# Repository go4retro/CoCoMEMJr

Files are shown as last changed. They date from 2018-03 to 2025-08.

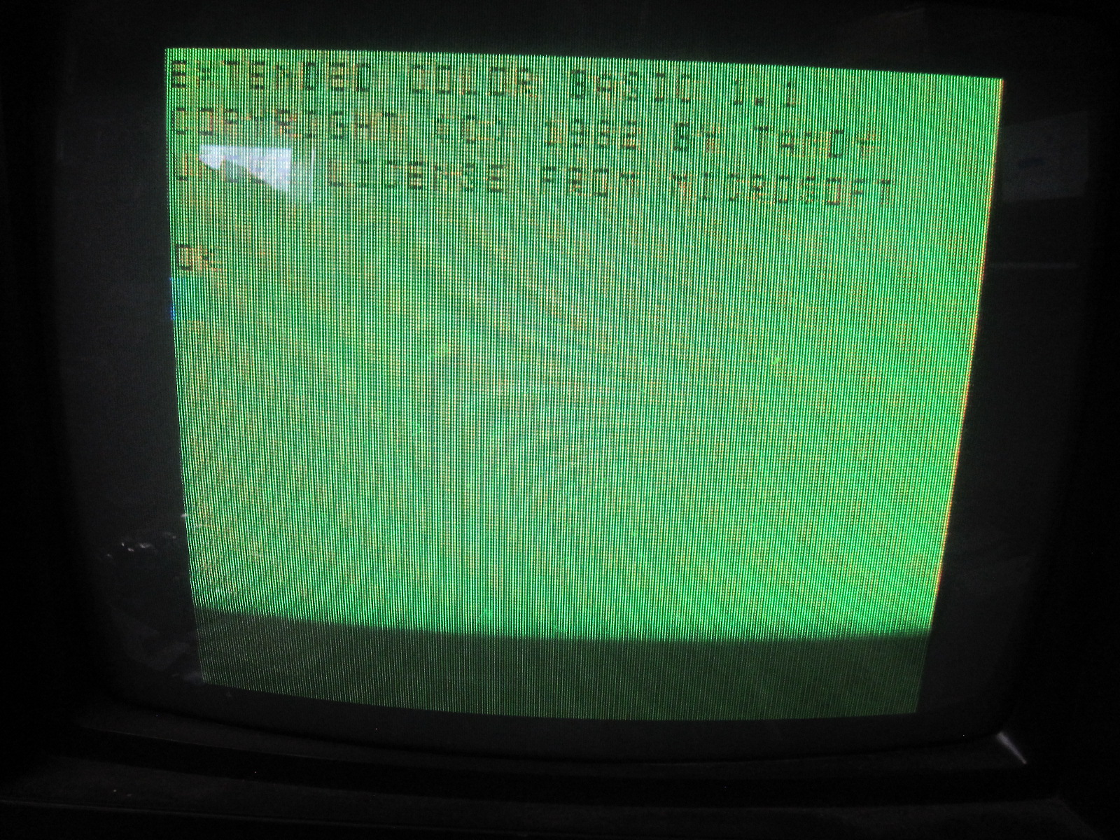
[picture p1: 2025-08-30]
media/IMG_8341.JPG

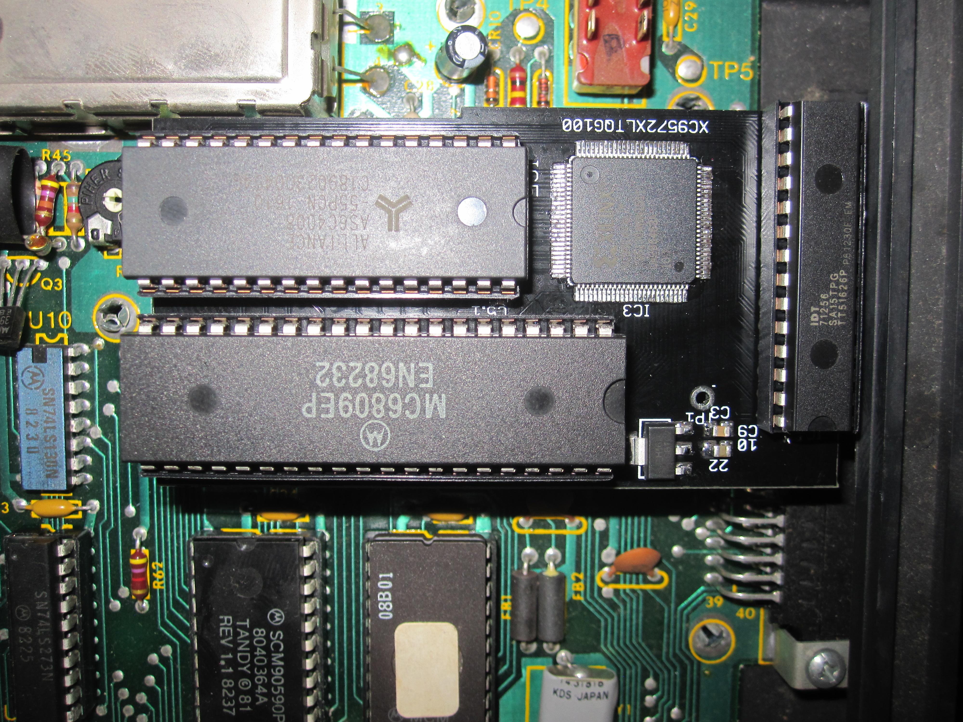
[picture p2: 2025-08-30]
media/IMG_8122.JPG

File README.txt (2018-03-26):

TANDY Color Computer 1 and 2/Dragon 2MB RAM Expansion System

Copyright (C) 2017-18  Jim Brain, RETRO Innovations

These files are free designs; you can redistribute them and/or modify
them under the terms of the Creative Commons Attribution-ShareAlike 
4.0 International License.

You should have received a copy of the license along with this
work. If not, see <http://creativecommons.org/licenses/by-sa/4.0/>.

These files are distributed in the hope that they will be useful,
but WITHOUT ANY WARRANTY; without even the implied warranty of
MERCHANTABILITY or FITNESS FOR A PARTICULAR PURPOSE.  See the
license for more details.

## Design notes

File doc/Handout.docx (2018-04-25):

COCOMEM Jr.

Memory expansion and MMU for the TANDY Color Computer™ 1 and 2 and Dragon Data™ 32/64 and TANO Dragon

# Features

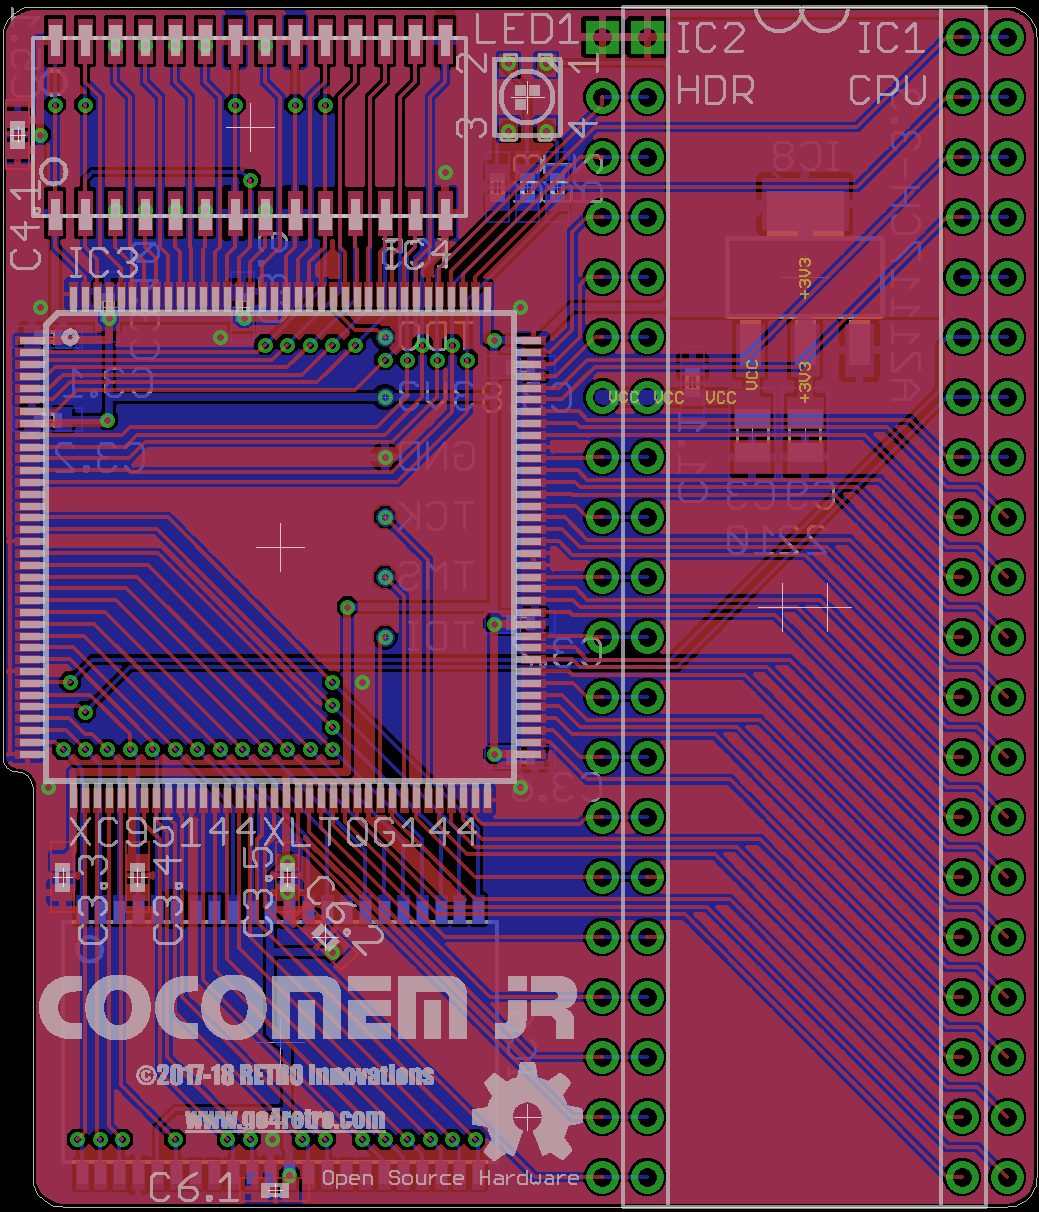
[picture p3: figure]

- 2 Megabyte RAM Expansion
- TANDY Color Computer™ 3-compatible MMU
- Installs internal to Color Computer (in CPU socket)
- CocoMEM MMU+ capability (32 tasks, protected memory)
- Internal Color Computer memory can be relocated via MMU

Offered by:

RETRO Innovations

Contemporary Gear for Classic Machines

www.go4retro.com

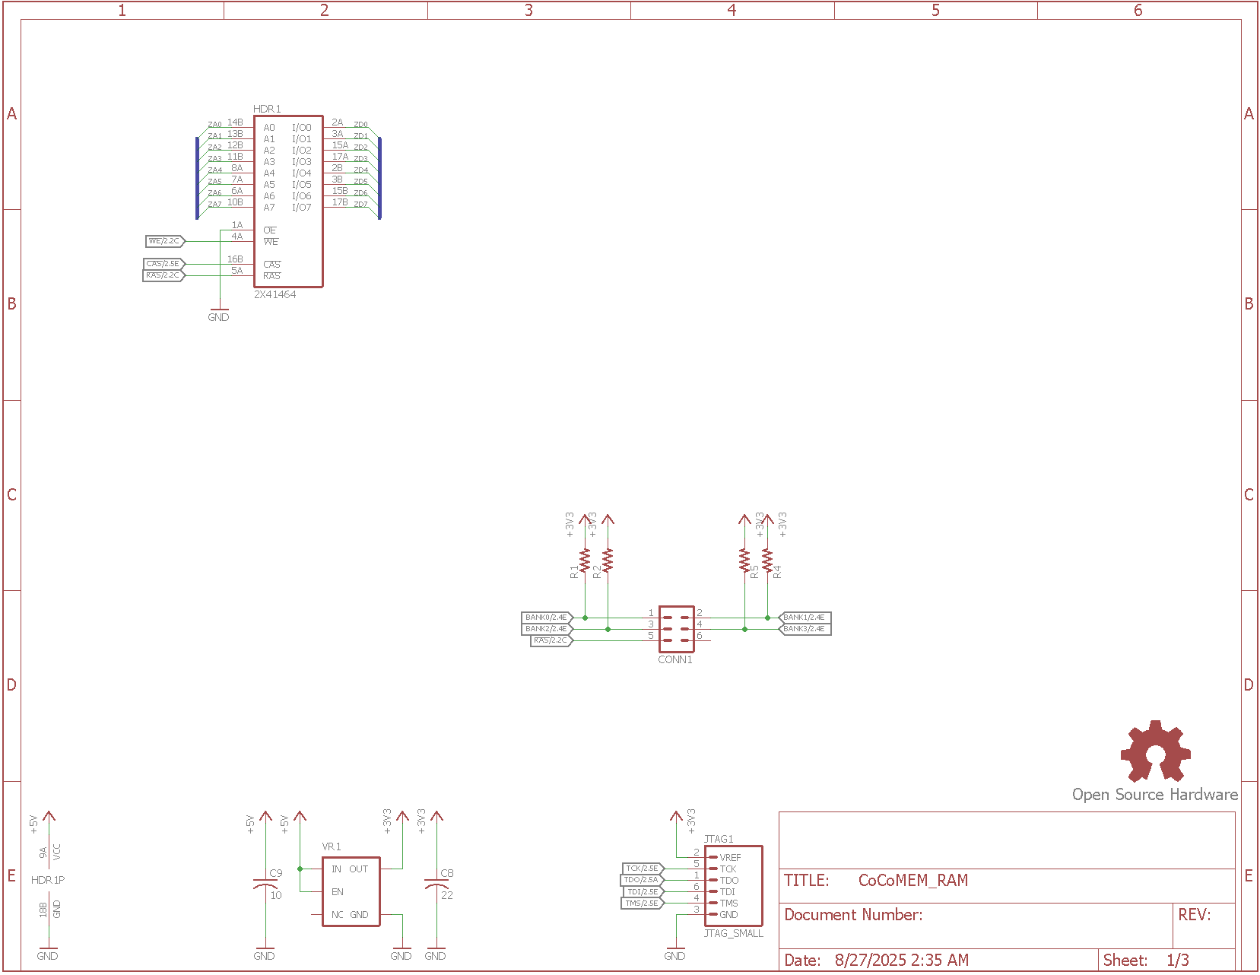
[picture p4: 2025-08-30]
media/CoCoMEM_RAM Schematic.png

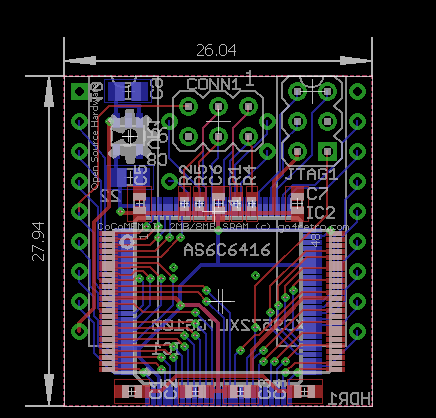
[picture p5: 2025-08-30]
media/CoCoMEM_RAM PCB.png

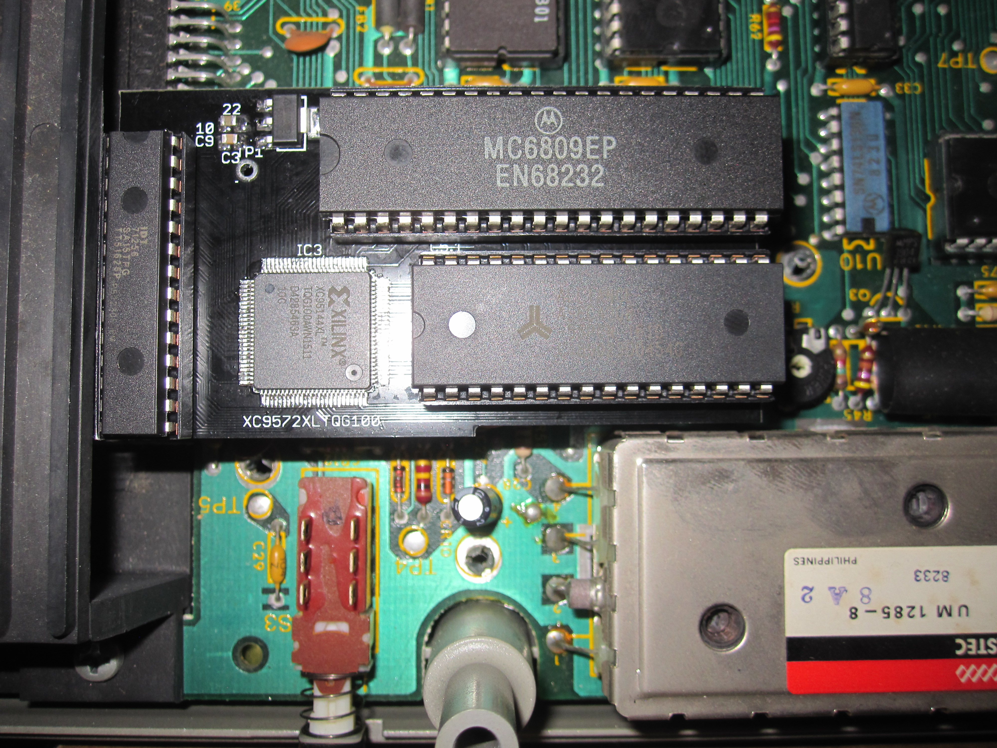
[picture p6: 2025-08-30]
media/IMG_8124 - Copy.JPG

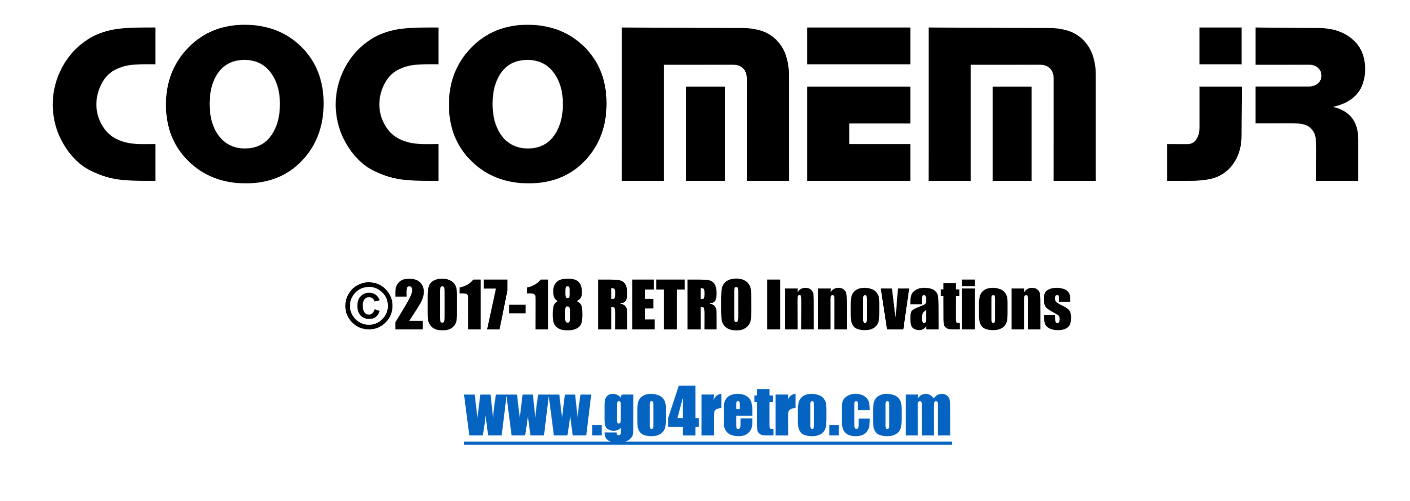
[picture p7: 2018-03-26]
pcb/CocoMemJr.PNG

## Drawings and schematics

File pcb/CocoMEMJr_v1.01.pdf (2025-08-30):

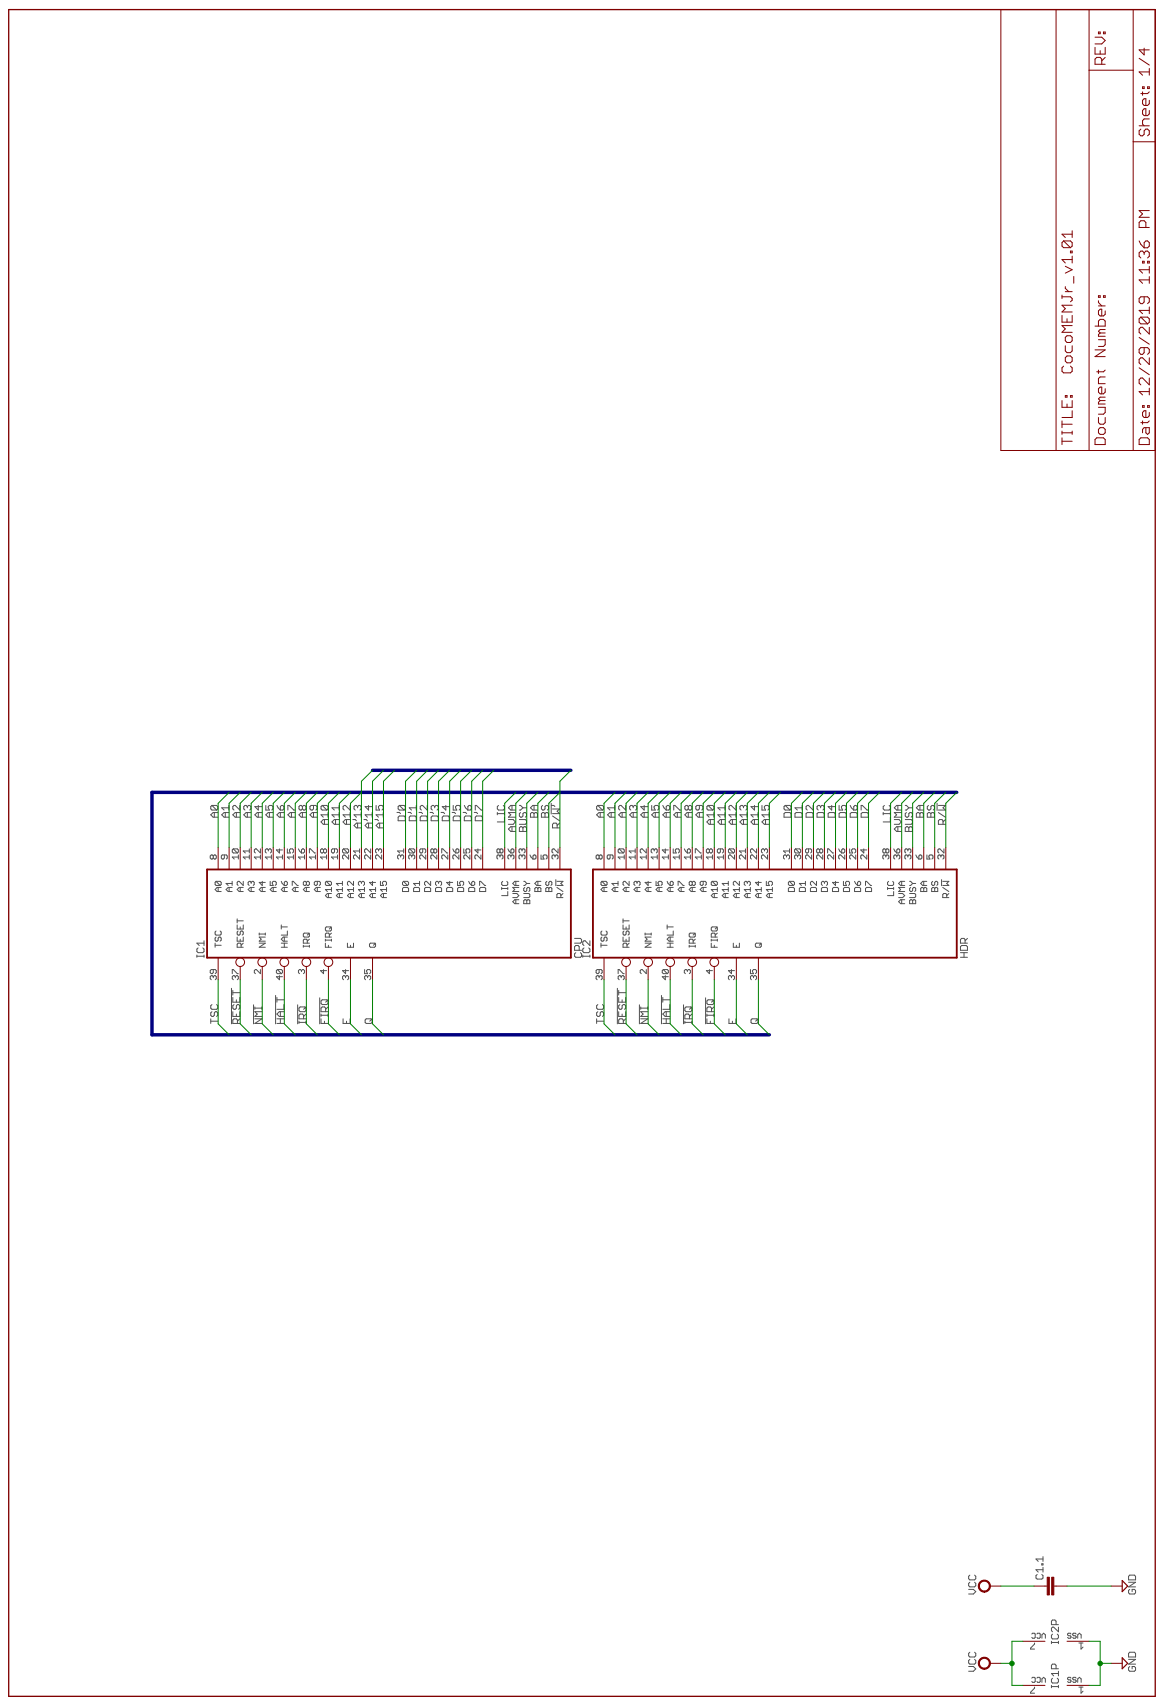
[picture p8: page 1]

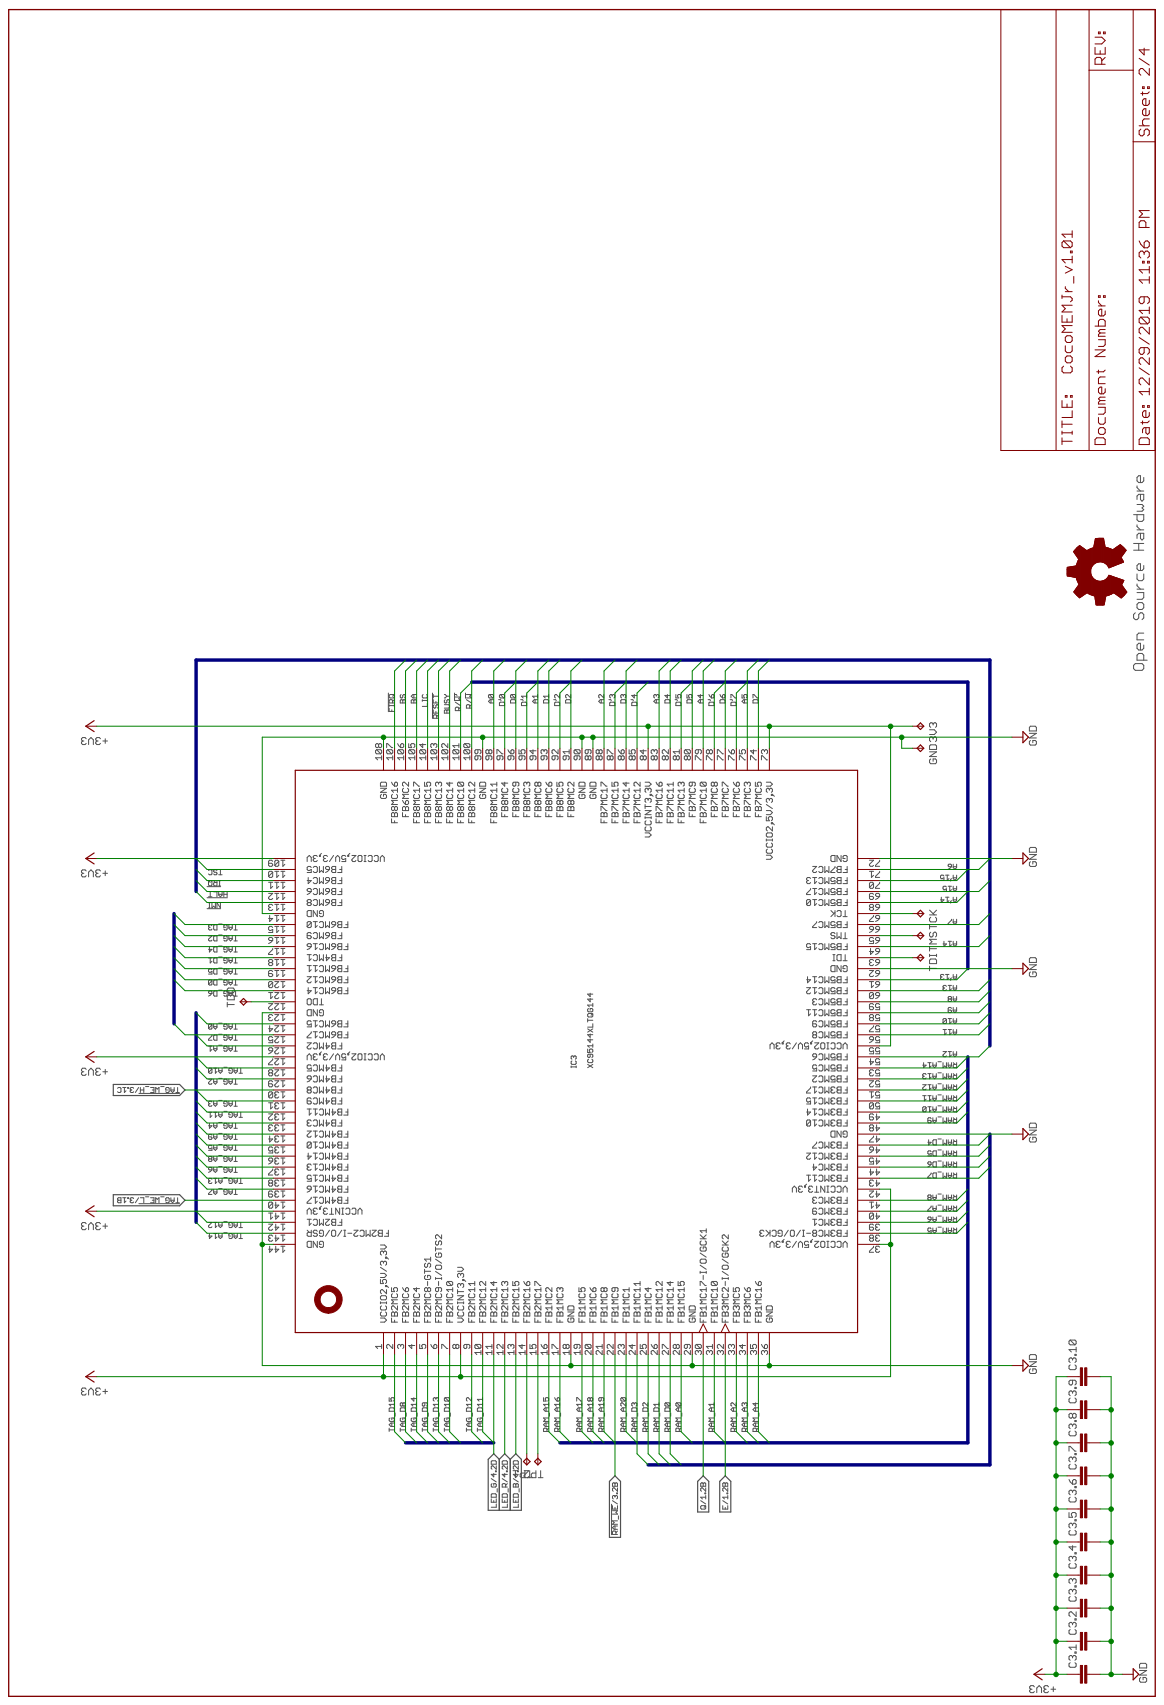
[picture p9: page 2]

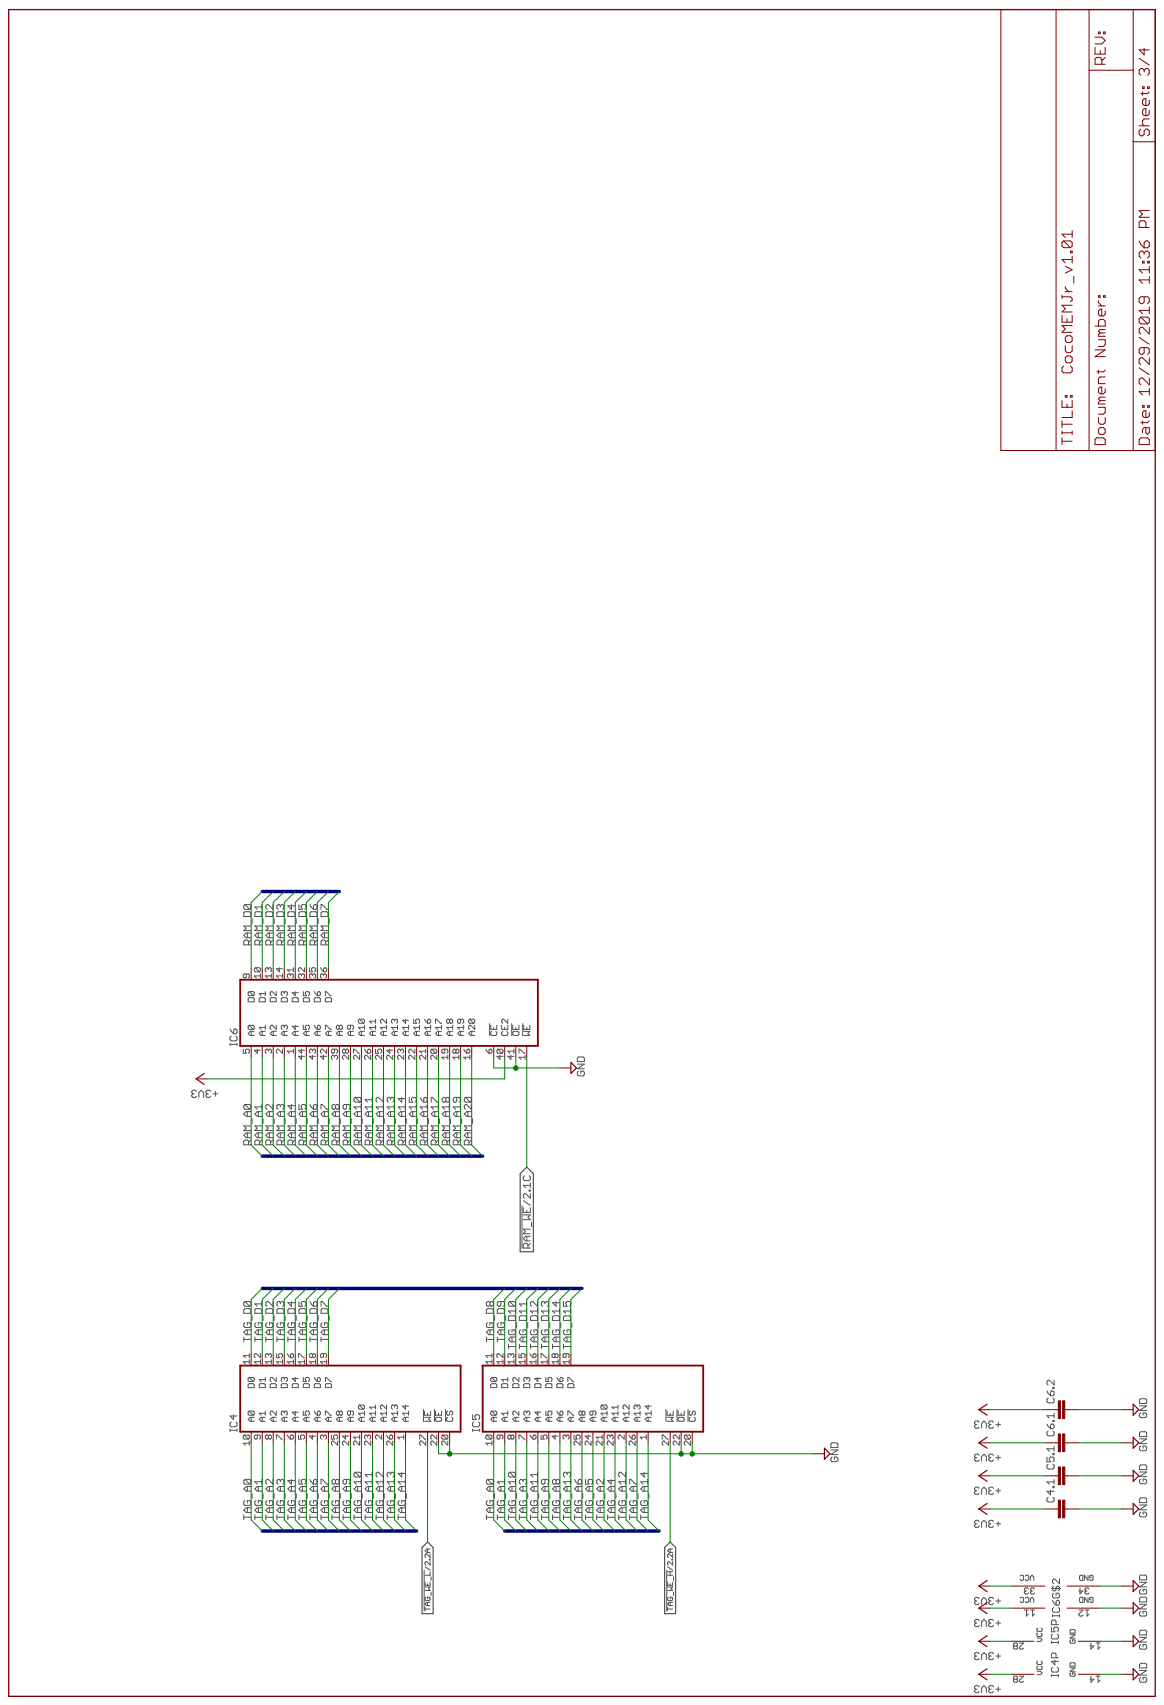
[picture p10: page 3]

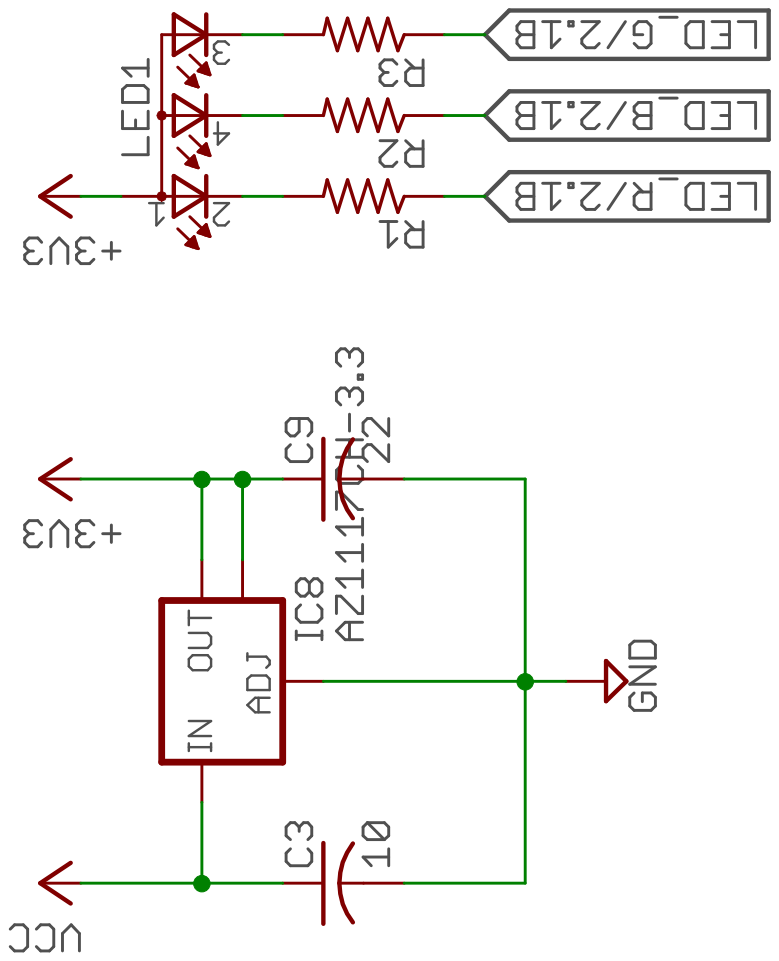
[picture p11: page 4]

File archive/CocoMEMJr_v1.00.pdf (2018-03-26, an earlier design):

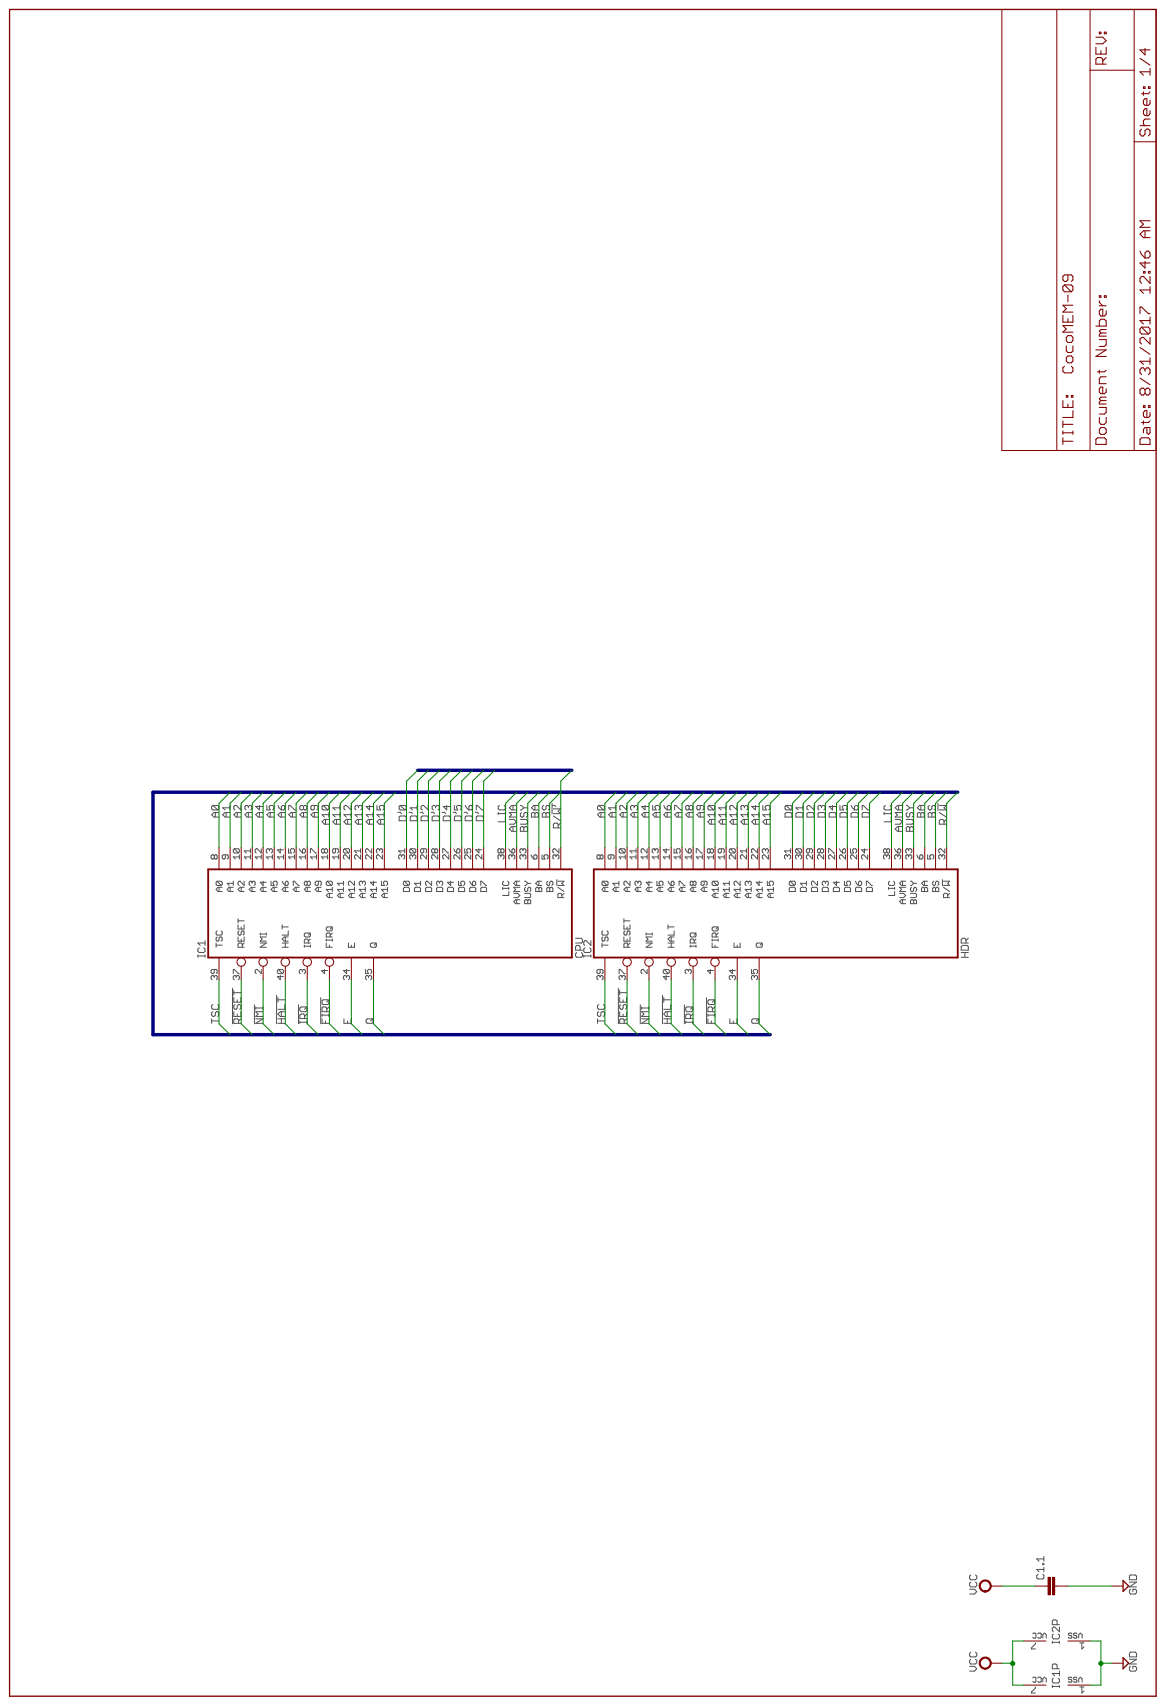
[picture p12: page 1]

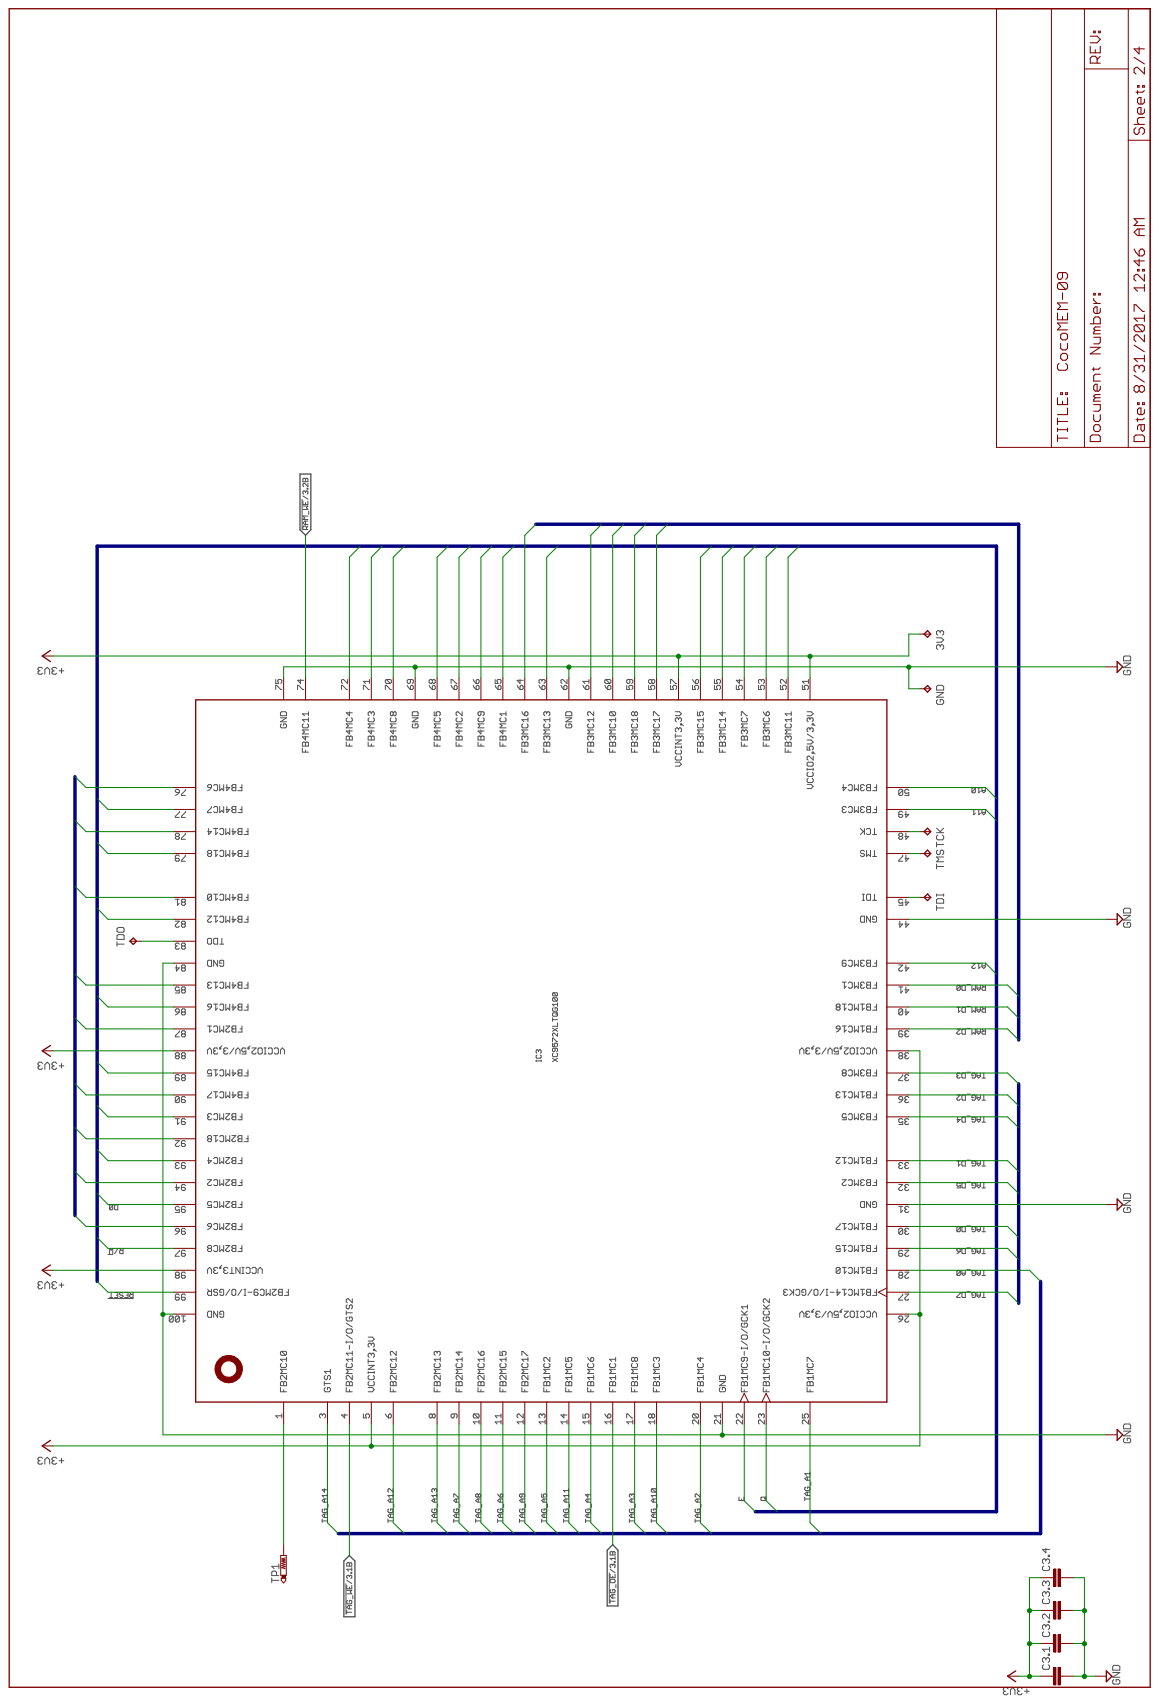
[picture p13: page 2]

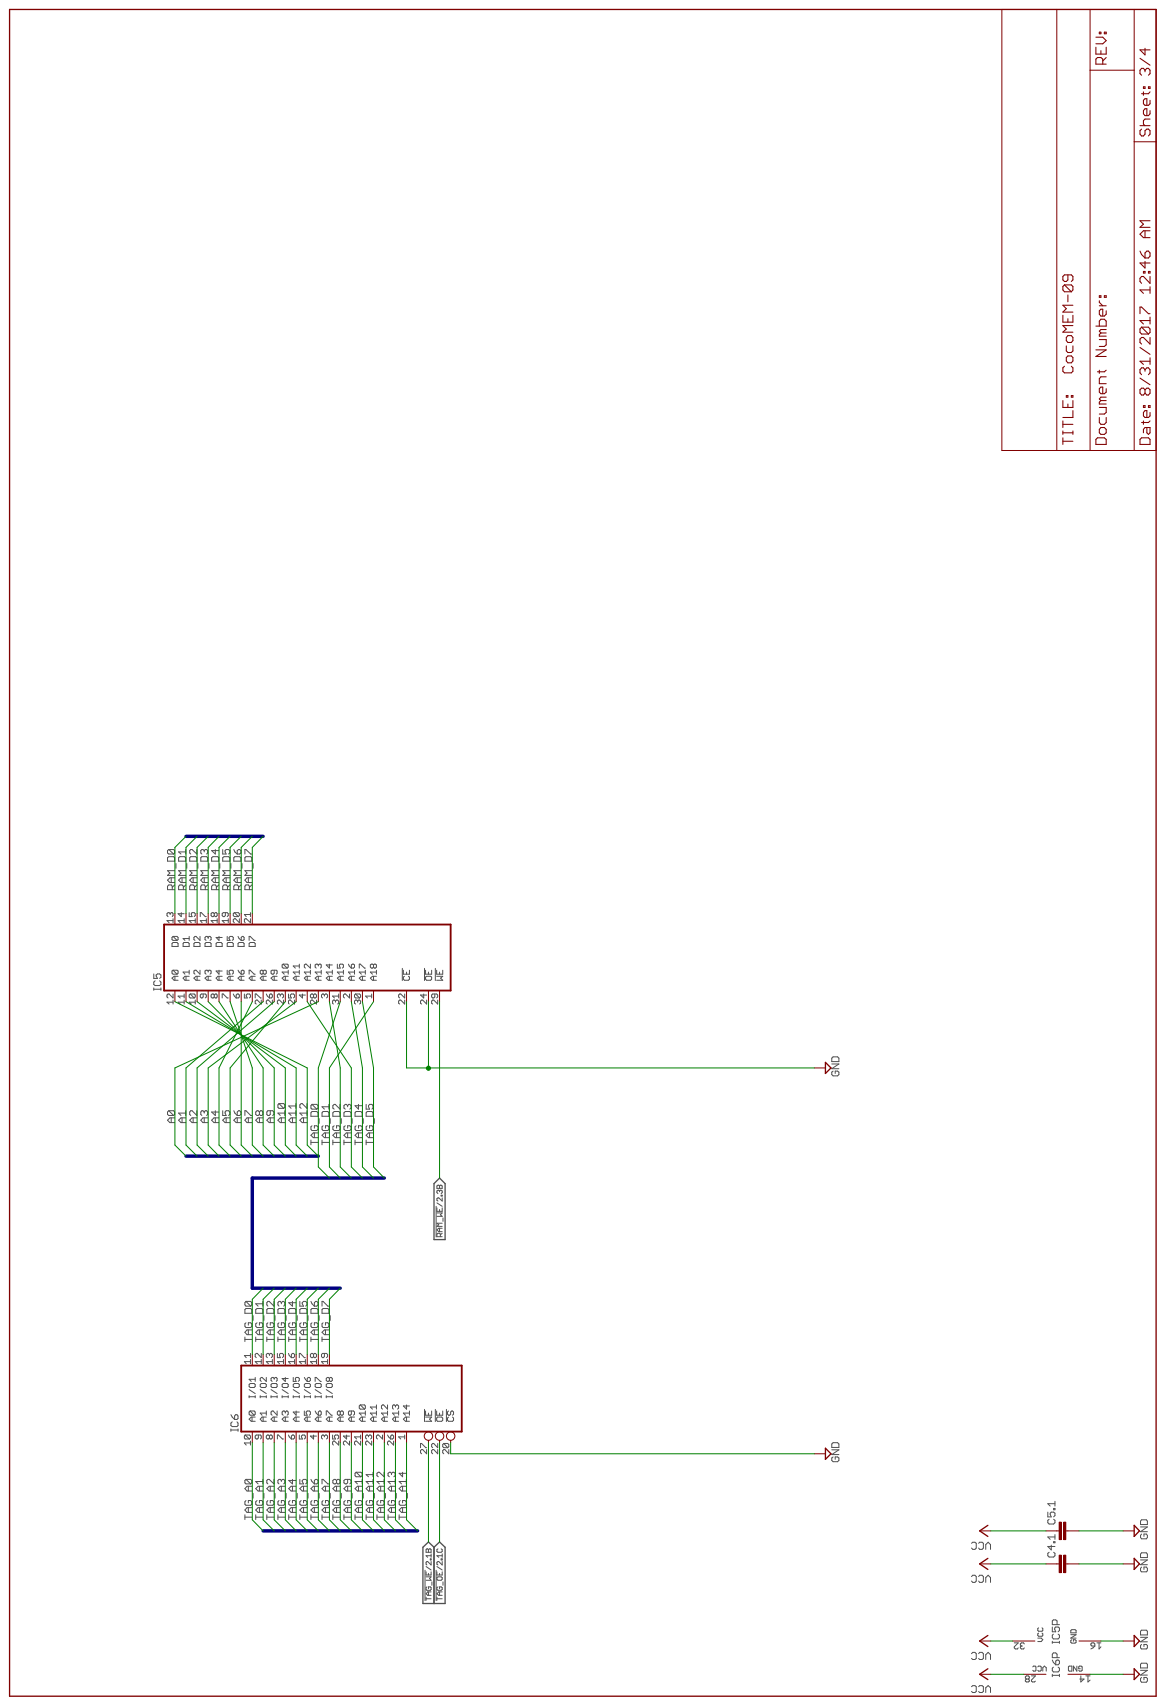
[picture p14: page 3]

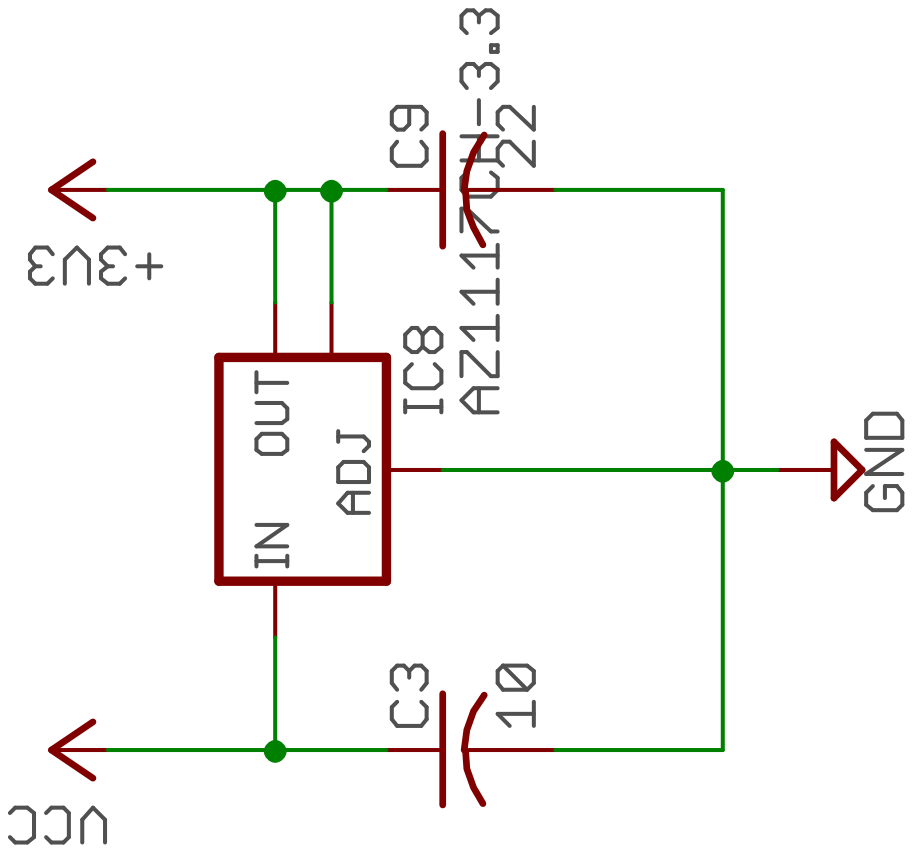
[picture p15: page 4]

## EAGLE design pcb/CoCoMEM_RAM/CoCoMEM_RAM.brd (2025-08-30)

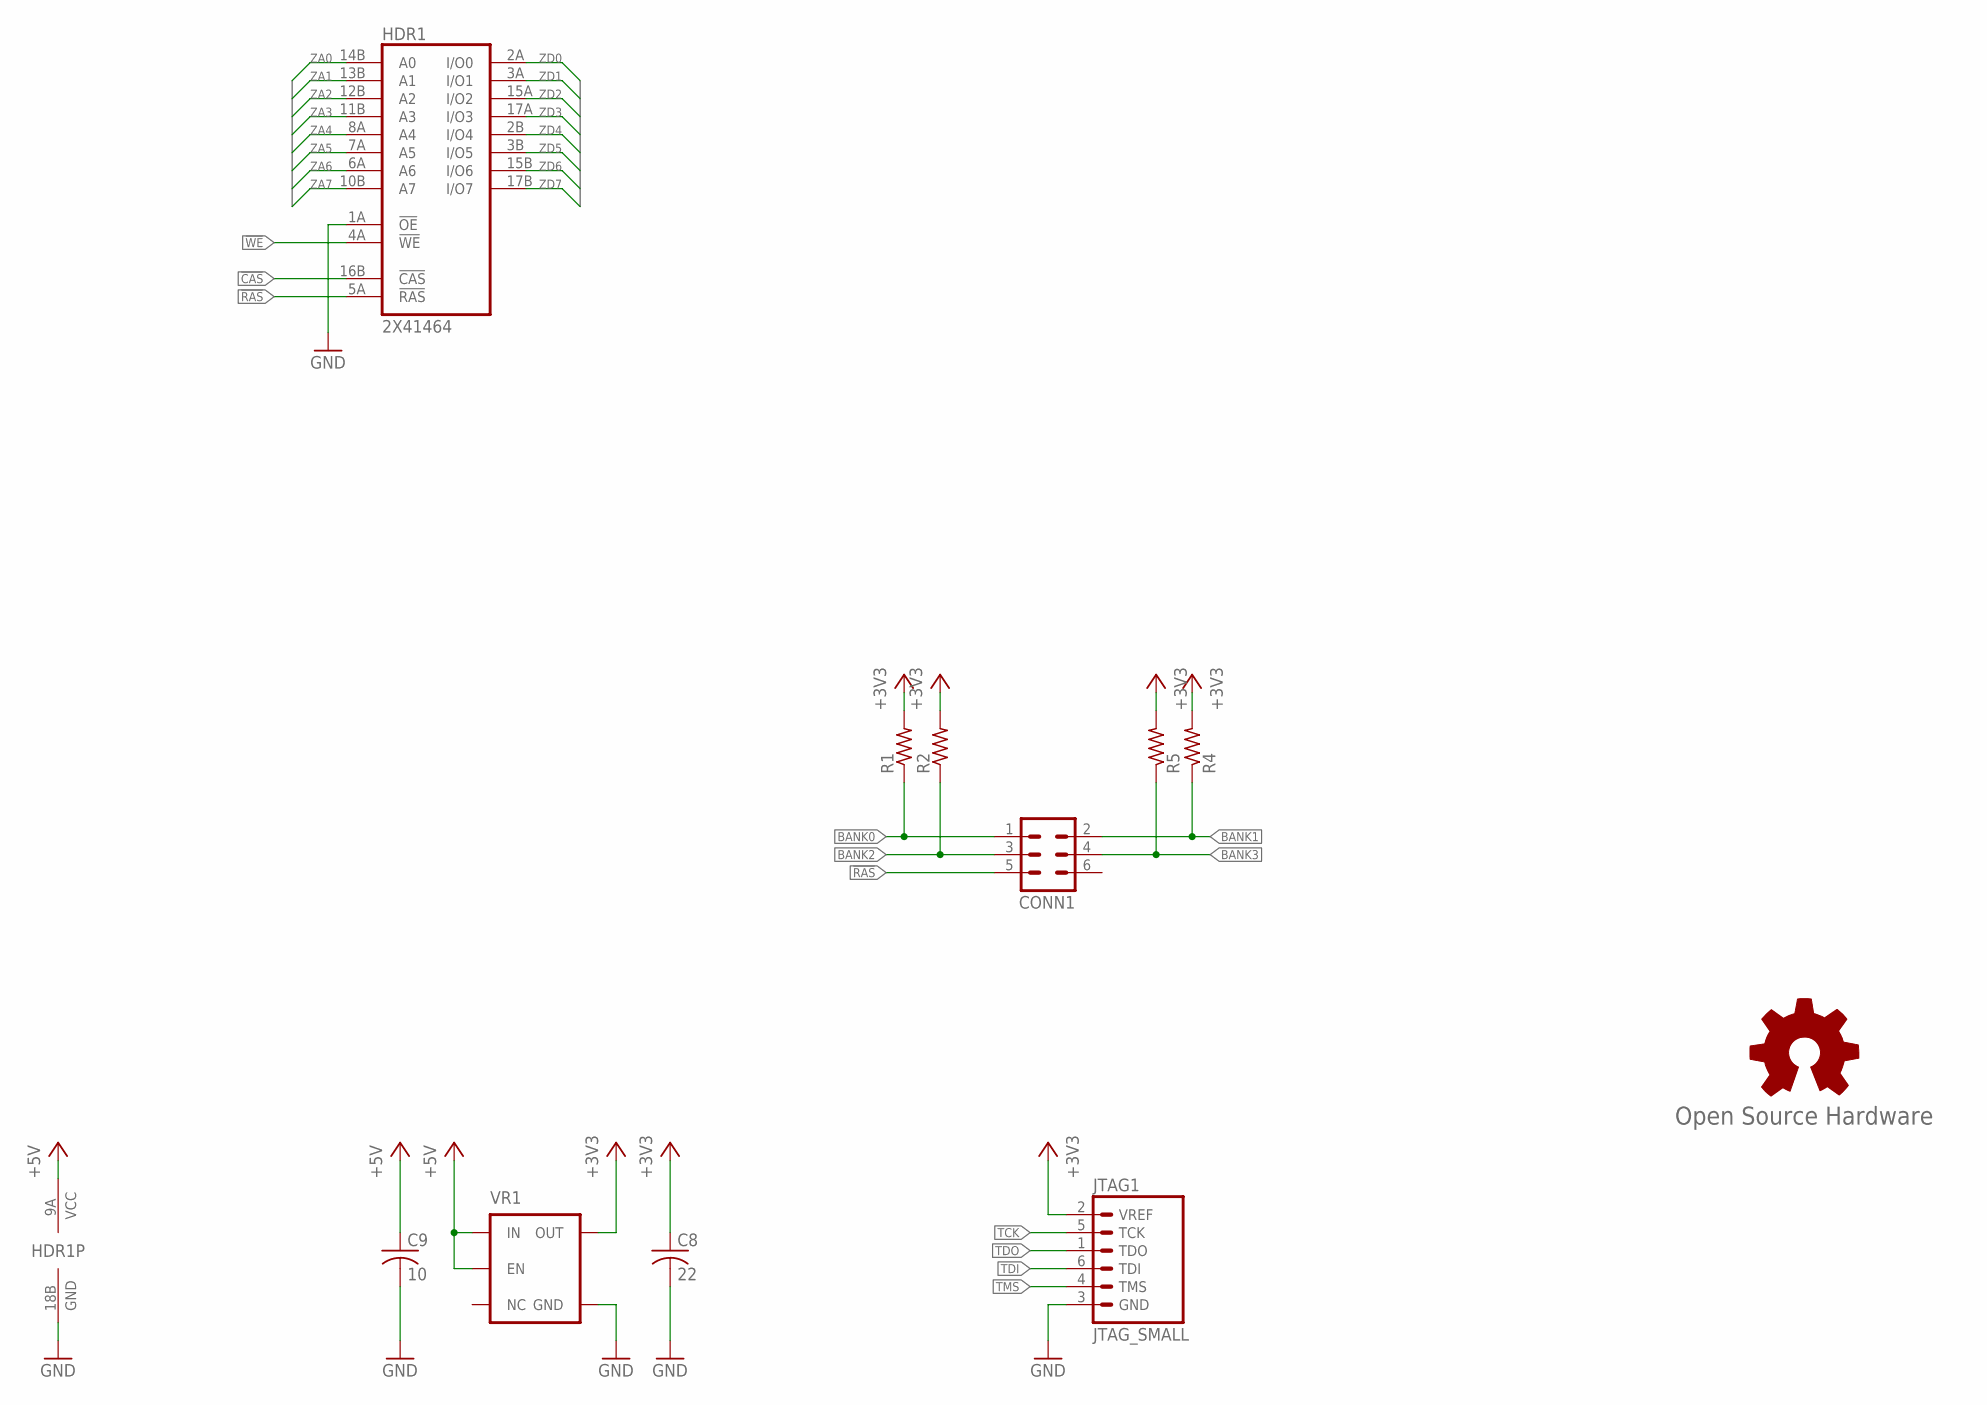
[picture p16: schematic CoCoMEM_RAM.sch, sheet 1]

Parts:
C8: 22; C0805
C9: 10; C0805
CONN1: MA03-2
GOLD_ORB_SM1: Open Source Hardware; OSHW_5MM
HDR1: 2X41464; 2XDIL18_REV
JTAG1: JTAG_SMALL; JTAG-6
R1, R2, R4, R5: R-US_R0402; R0402
VR1: V_REG_TPS76433SOT23-5; SOT23-5

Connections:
!CAS: HDR1.16B (!CAS); also elsewhere on the board
!RAS: CONN1.5, HDR1.5A (!RAS); also elsewhere on the board
!WE: HDR1.4A (!WE); also elsewhere on the board
+3V3: C8.1, JTAG1.2 (VREF), R1.2, R2.2, R4.2, R5.2, VR1.5 (OUT); also elsewhere on the board
+5V: C9.1, HDR1.9A (VCC), VR1.1 (IN), VR1.3 (EN)
BANK0: CONN1.1, R1.1; also elsewhere on the board
BANK1: CONN1.2, R4.1; also elsewhere on the board
BANK2: CONN1.3, R2.1; also elsewhere on the board
BANK3: CONN1.4, R5.1; also elsewhere on the board
GND: C8.2, C9.2, HDR1.1A (!OE), HDR1.18B (GND), JTAG1.3 (GND), VR1.2 (GND); also elsewhere on the board
TCK: JTAG1.5 (TCK); also elsewhere on the board
TDI: JTAG1.6 (TDI); also elsewhere on the board
TDO: JTAG1.1 (TDO); also elsewhere on the board
TMS: JTAG1.4 (TMS); also elsewhere on the board
ZA0: HDR1.14B (A0); also elsewhere on the board
ZA1: HDR1.13B (A1); also elsewhere on the board
ZA2: HDR1.12B (A2); also elsewhere on the board
ZA3: HDR1.11B (A3); also elsewhere on the board
ZA4: HDR1.8A (A4); also elsewhere on the board
ZA5: HDR1.7A (A5); also elsewhere on the board
ZA6: HDR1.6A (A6); also elsewhere on the board
ZA7: HDR1.10B (A7); also elsewhere on the board
ZD0: HDR1.2A (I/O0); also elsewhere on the board
ZD1: HDR1.3A (I/O1); also elsewhere on the board
ZD2: HDR1.15A (I/O2); also elsewhere on the board
ZD3: HDR1.17A (I/O3); also elsewhere on the board
ZD4: HDR1.2B (I/O4); also elsewhere on the board
ZD5: HDR1.3B (I/O5); also elsewhere on the board
ZD6: HDR1.15B (I/O6); also elsewhere on the board
ZD7: HDR1.17B (I/O7); also elsewhere on the board

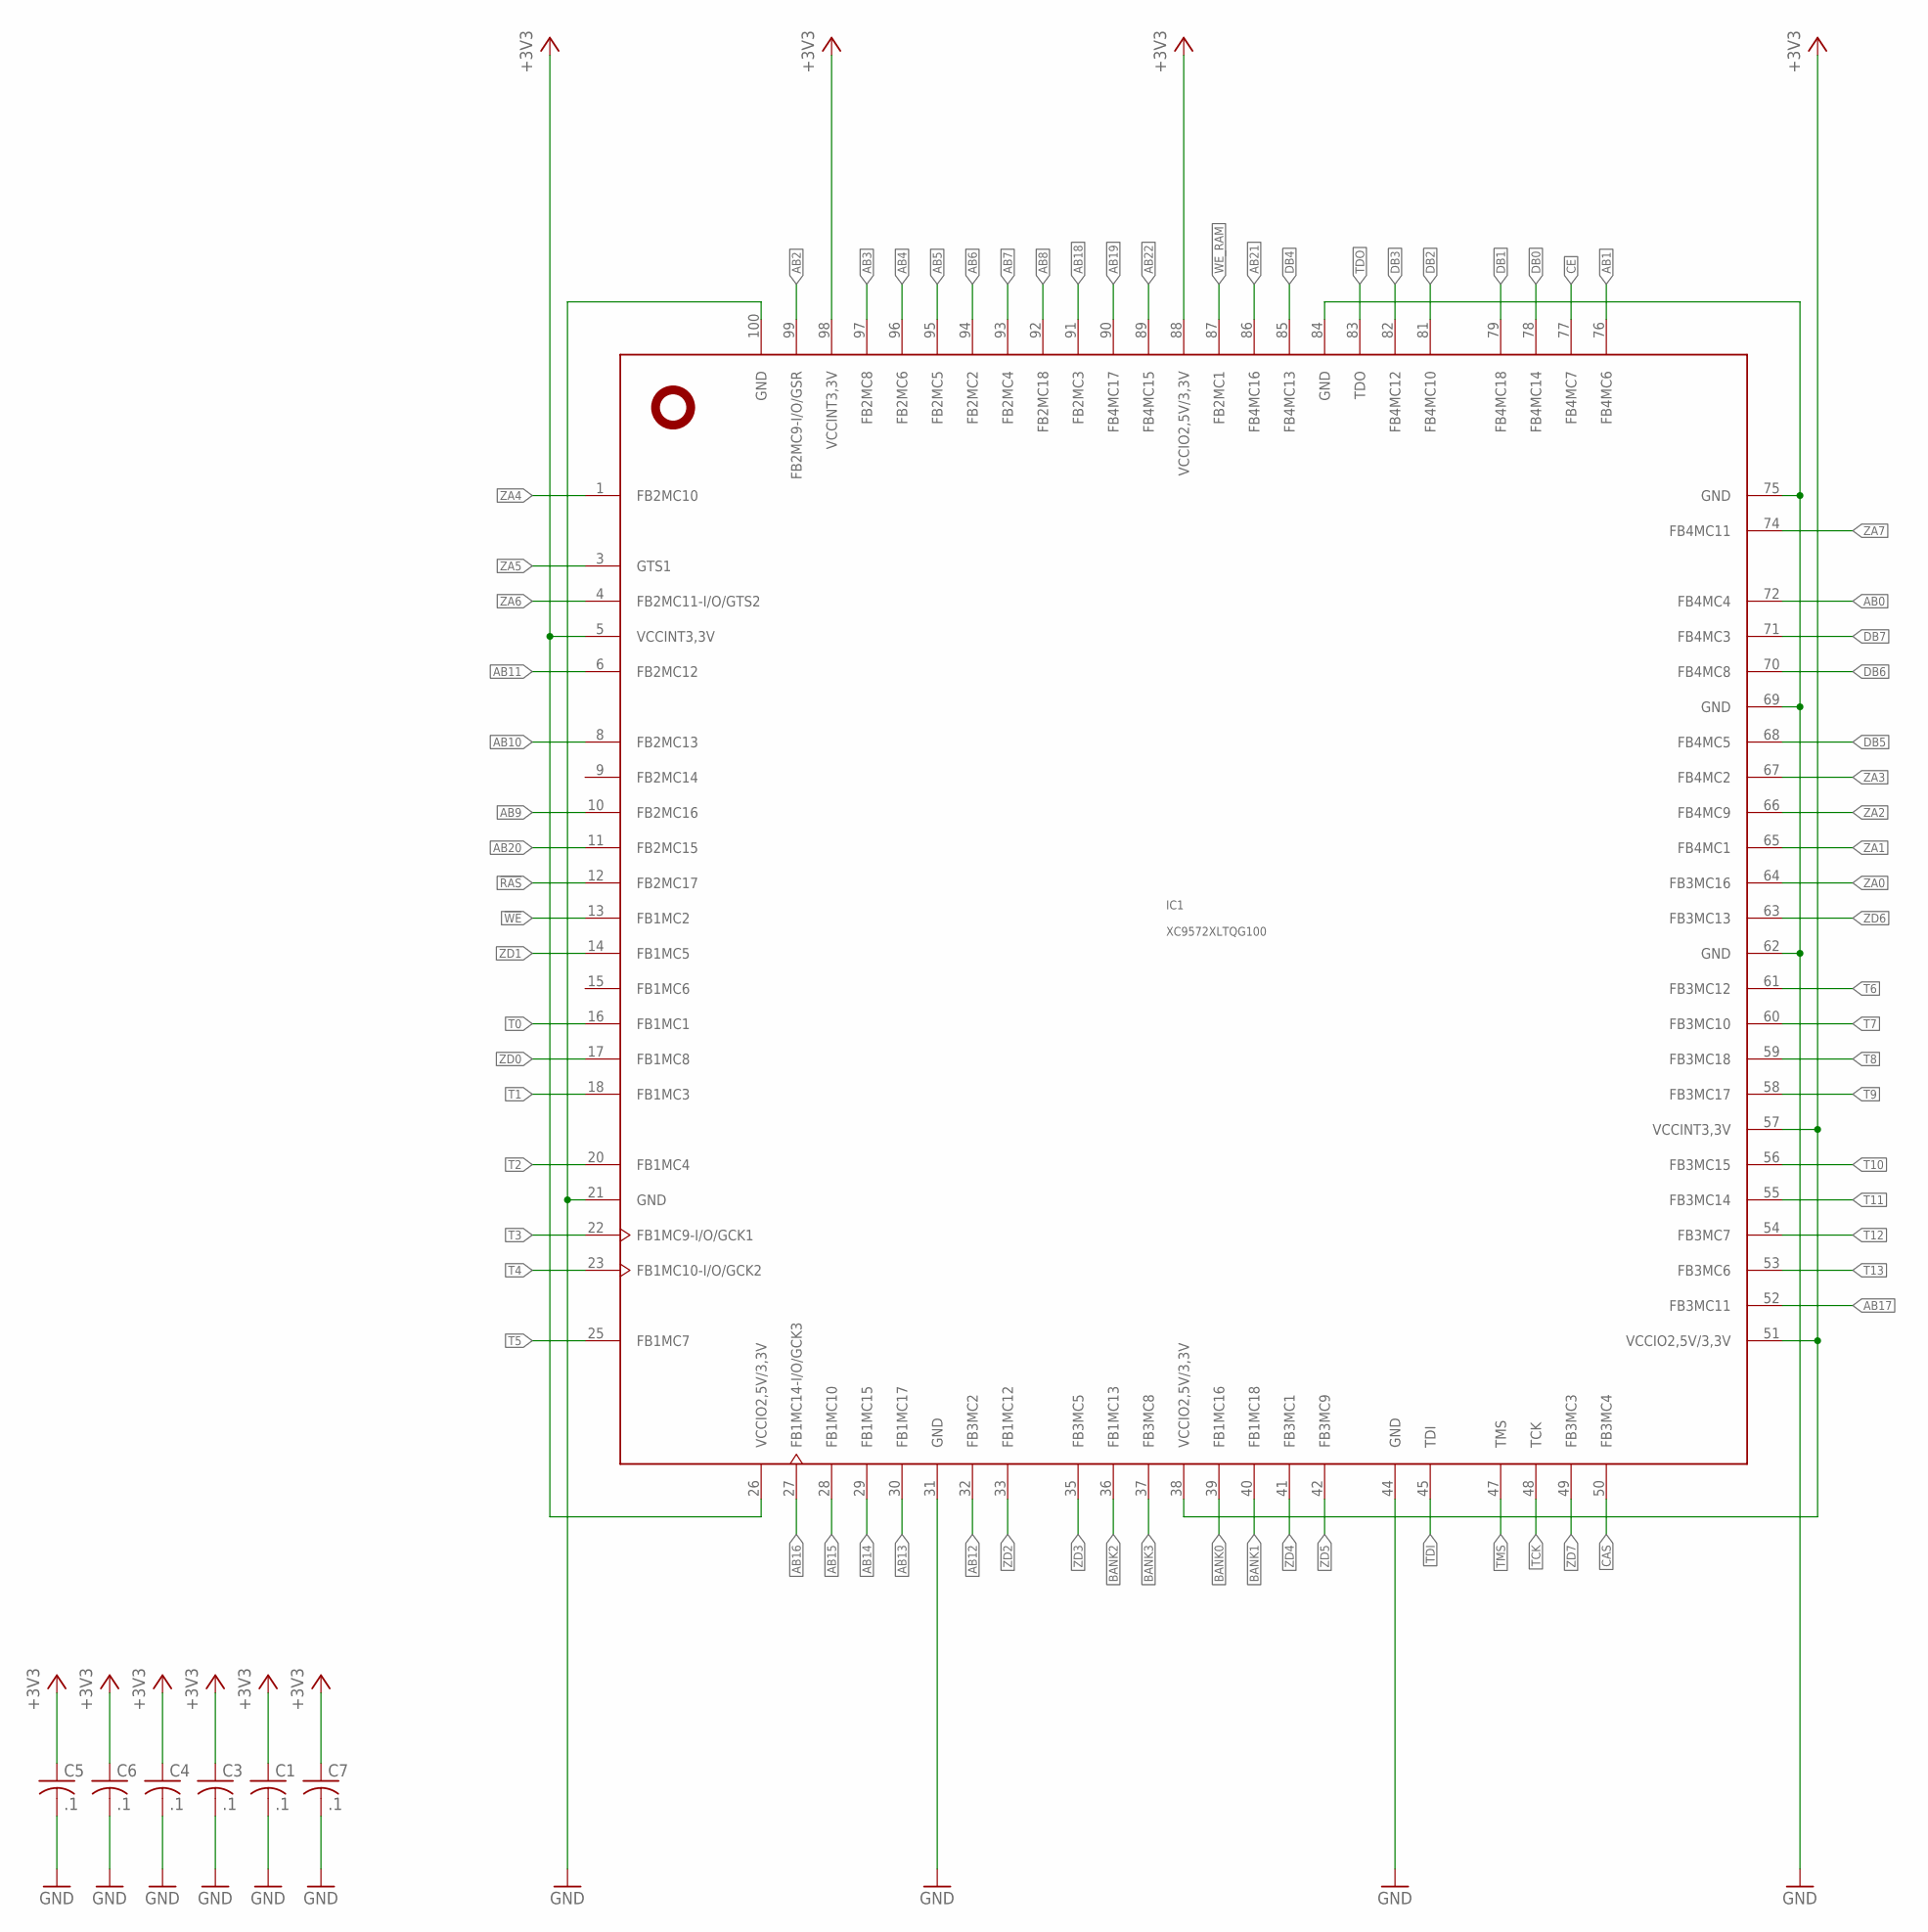
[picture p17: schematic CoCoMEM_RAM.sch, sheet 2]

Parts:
C1, C3, C4, C5, C6, C7: .1; C0603
IC1: XC9572XLTQG100; TQFP100

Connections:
!CAS: IC1.50 (FB3MC4); also elsewhere on the board
!CE: IC1.77 (FB4MC7); also elsewhere on the board
!RAS: IC1.12 (FB2MC17); also elsewhere on the board
!WE: IC1.13 (FB1MC2); also elsewhere on the board
!WE_RAM: IC1.87 (FB2MC1); also elsewhere on the board
+3V3: C1.1, C3.1, C4.1, C5.1, C6.1, C7.1, IC1.5 (VCCINT3,3V), IC1.26 (VCCIO2,5V/3,3V), IC1.38 (VCCIO2,5V/3,3V), IC1.51 (VCCIO2,5V/3,3V), IC1.57 (VCCINT3,3V), IC1.88 (VCCIO2,5V/3,3V), IC1.98 (VCCINT3,3V); also elsewhere on the board
AB0: IC1.72 (FB4MC4); also elsewhere on the board
AB1: IC1.76 (FB4MC6); also elsewhere on the board
AB2: IC1.99 (FB2MC9-I/O/GSR); also elsewhere on the board
AB3: IC1.97 (FB2MC8); also elsewhere on the board
AB4: IC1.96 (FB2MC6); also elsewhere on the board
AB5: IC1.95 (FB2MC5); also elsewhere on the board
AB6: IC1.94 (FB2MC2); also elsewhere on the board
AB7: IC1.93 (FB2MC4); also elsewhere on the board
AB8: IC1.92 (FB2MC18); also elsewhere on the board
AB9: IC1.10 (FB2MC16); also elsewhere on the board
AB10: IC1.8 (FB2MC13); also elsewhere on the board
AB11: IC1.6 (FB2MC12); also elsewhere on the board
AB12: IC1.32 (FB3MC2); also elsewhere on the board
AB13: IC1.30 (FB1MC17); also elsewhere on the board
AB14: IC1.29 (FB1MC15); also elsewhere on the board
AB15: IC1.28 (FB1MC10); also elsewhere on the board
AB16: IC1.27 (FB1MC14-I/O/GCK3); also elsewhere on the board
AB17: IC1.52 (FB3MC11); also elsewhere on the board
AB18: IC1.91 (FB2MC3); also elsewhere on the board
AB19: IC1.90 (FB4MC17); also elsewhere on the board
AB20: IC1.11 (FB2MC15); also elsewhere on the board
AB21: IC1.86 (FB4MC16); also elsewhere on the board
AB22: IC1.89 (FB4MC15); also elsewhere on the board
BANK0: IC1.39 (FB1MC16); also elsewhere on the board
BANK1: IC1.40 (FB1MC18); also elsewhere on the board
BANK2: IC1.36 (FB1MC13); also elsewhere on the board
BANK3: IC1.37 (FB3MC8); also elsewhere on the board
DB0: IC1.78 (FB4MC14); also elsewhere on the board
DB1: IC1.79 (FB4MC18); also elsewhere on the board
DB2: IC1.81 (FB4MC10); also elsewhere on the board
DB3: IC1.82 (FB4MC12); also elsewhere on the board
DB4: IC1.85 (FB4MC13); also elsewhere on the board
DB5: IC1.68 (FB4MC5); also elsewhere on the board
DB6: IC1.70 (FB4MC8); also elsewhere on the board
DB7: IC1.71 (FB4MC3); also elsewhere on the board
GND: C1.2, C3.2, C4.2, C5.2, C6.2, C7.2, IC1.21 (GND), IC1.31 (GND), IC1.44 (GND), IC1.62 (GND), IC1.69 (GND), IC1.75 (GND), IC1.84 (GND), IC1.100 (GND); also elsewhere on the board
T0: IC1.16 (FB1MC1)
T1: IC1.18 (FB1MC3)
T2: IC1.20 (FB1MC4)
T3: IC1.22 (FB1MC9-I/O/GCK1)
T4: IC1.23 (FB1MC10-I/O/GCK2)
T5: IC1.25 (FB1MC7)
T6: IC1.61 (FB3MC12)
T7: IC1.60 (FB3MC10)
T8: IC1.59 (FB3MC18)
T9: IC1.58 (FB3MC17)
T10: IC1.56 (FB3MC15)
T11: IC1.55 (FB3MC14)
T12: IC1.54 (FB3MC7)
T13: IC1.53 (FB3MC6)
TCK: IC1.48 (TCK); also elsewhere on the board
TDI: IC1.45 (TDI); also elsewhere on the board
TDO: IC1.83 (TDO); also elsewhere on the board
TMS: IC1.47 (TMS); also elsewhere on the board
ZA0: IC1.64 (FB3MC16); also elsewhere on the board
ZA1: IC1.65 (FB4MC1); also elsewhere on the board
ZA2: IC1.66 (FB4MC9); also elsewhere on the board
ZA3: IC1.67 (FB4MC2); also elsewhere on the board
ZA4: IC1.1 (FB2MC10); also elsewhere on the board
ZA5: IC1.3 (GTS1); also elsewhere on the board
ZA6: IC1.4 (FB2MC11-I/O/GTS2); also elsewhere on the board
ZA7: IC1.74 (FB4MC11); also elsewhere on the board
ZD0: IC1.17 (FB1MC8); also elsewhere on the board
ZD1: IC1.14 (FB1MC5); also elsewhere on the board
ZD2: IC1.33 (FB1MC12); also elsewhere on the board
ZD3: IC1.35 (FB3MC5); also elsewhere on the board
ZD4: IC1.41 (FB3MC1); also elsewhere on the board
ZD5: IC1.42 (FB3MC9); also elsewhere on the board
ZD6: IC1.63 (FB3MC13); also elsewhere on the board
ZD7: IC1.49 (FB3MC3); also elsewhere on the board

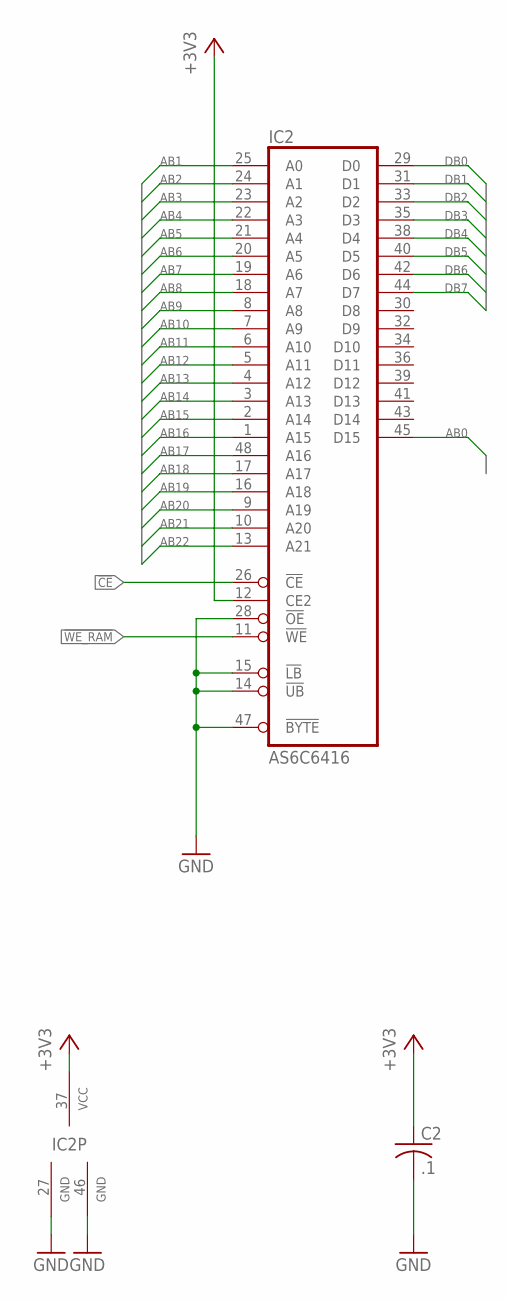
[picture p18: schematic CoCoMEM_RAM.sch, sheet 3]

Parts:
C2: .1; C0603
IC2: AS6C6416; TSOP48

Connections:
!CE: IC2.26 (!CE); also elsewhere on the board
!WE_RAM: IC2.11 (!WE); also elsewhere on the board
+3V3: C2.1, IC2.12 (CE2), IC2.37 (VCC); also elsewhere on the board
AB0: IC2.45 (D15); also elsewhere on the board
AB1: IC2.25 (A0); also elsewhere on the board
AB2: IC2.24 (A1); also elsewhere on the board
AB3: IC2.23 (A2); also elsewhere on the board
AB4: IC2.22 (A3); also elsewhere on the board
AB5: IC2.21 (A4); also elsewhere on the board
AB6: IC2.20 (A5); also elsewhere on the board
AB7: IC2.19 (A6); also elsewhere on the board
AB8: IC2.18 (A7); also elsewhere on the board
AB9: IC2.8 (A8); also elsewhere on the board
AB10: IC2.7 (A9); also elsewhere on the board
AB11: IC2.6 (A10); also elsewhere on the board
AB12: IC2.5 (A11); also elsewhere on the board
AB13: IC2.4 (A12); also elsewhere on the board
AB14: IC2.3 (A13); also elsewhere on the board
AB15: IC2.2 (A14); also elsewhere on the board
AB16: IC2.1 (A15); also elsewhere on the board
AB17: IC2.48 (A16); also elsewhere on the board
AB18: IC2.17 (A17); also elsewhere on the board
AB19: IC2.16 (A18); also elsewhere on the board
AB20: IC2.9 (A19); also elsewhere on the board
AB21: IC2.10 (A20); also elsewhere on the board
AB22: IC2.13 (A21); also elsewhere on the board
DB0: IC2.29 (D0); also elsewhere on the board
DB1: IC2.31 (D1); also elsewhere on the board
DB2: IC2.33 (D2); also elsewhere on the board
DB3: IC2.35 (D3); also elsewhere on the board
DB4: IC2.38 (D4); also elsewhere on the board
DB5: IC2.40 (D5); also elsewhere on the board
DB6: IC2.42 (D6); also elsewhere on the board
DB7: IC2.44 (D7); also elsewhere on the board
GND: C2.2, IC2.14 (!UB), IC2.15 (!LB), IC2.27 (GND), IC2.28 (!OE), IC2.46 (GND), IC2.47 (!BYTE); also elsewhere on the board

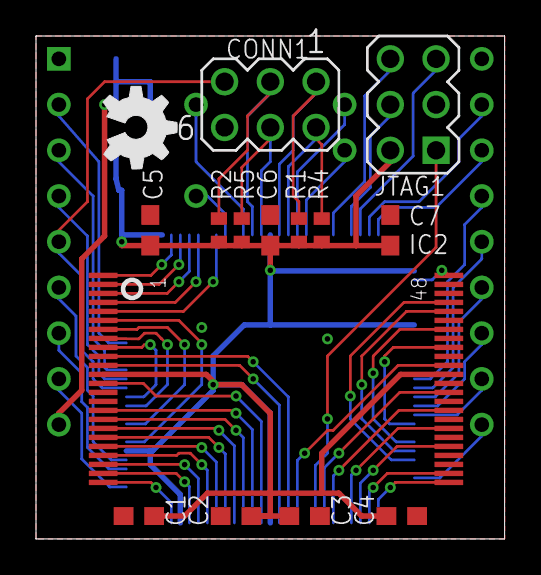
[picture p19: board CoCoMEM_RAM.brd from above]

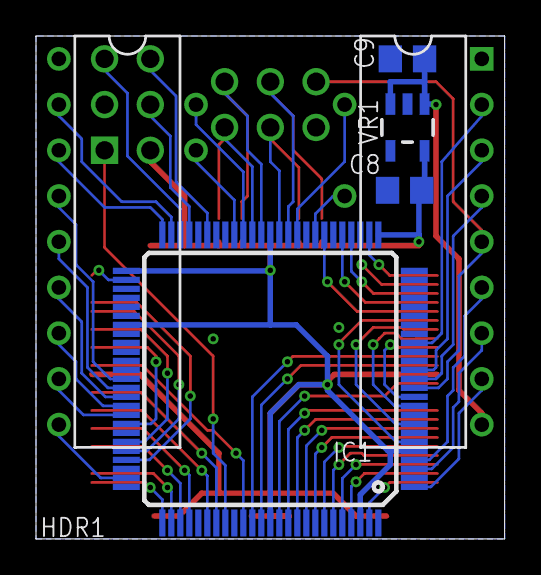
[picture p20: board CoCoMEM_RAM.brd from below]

Board: 2 copper layers, 26.0 x 27.9 mm, 20 parts (4 on the bottom side), 63 nets.

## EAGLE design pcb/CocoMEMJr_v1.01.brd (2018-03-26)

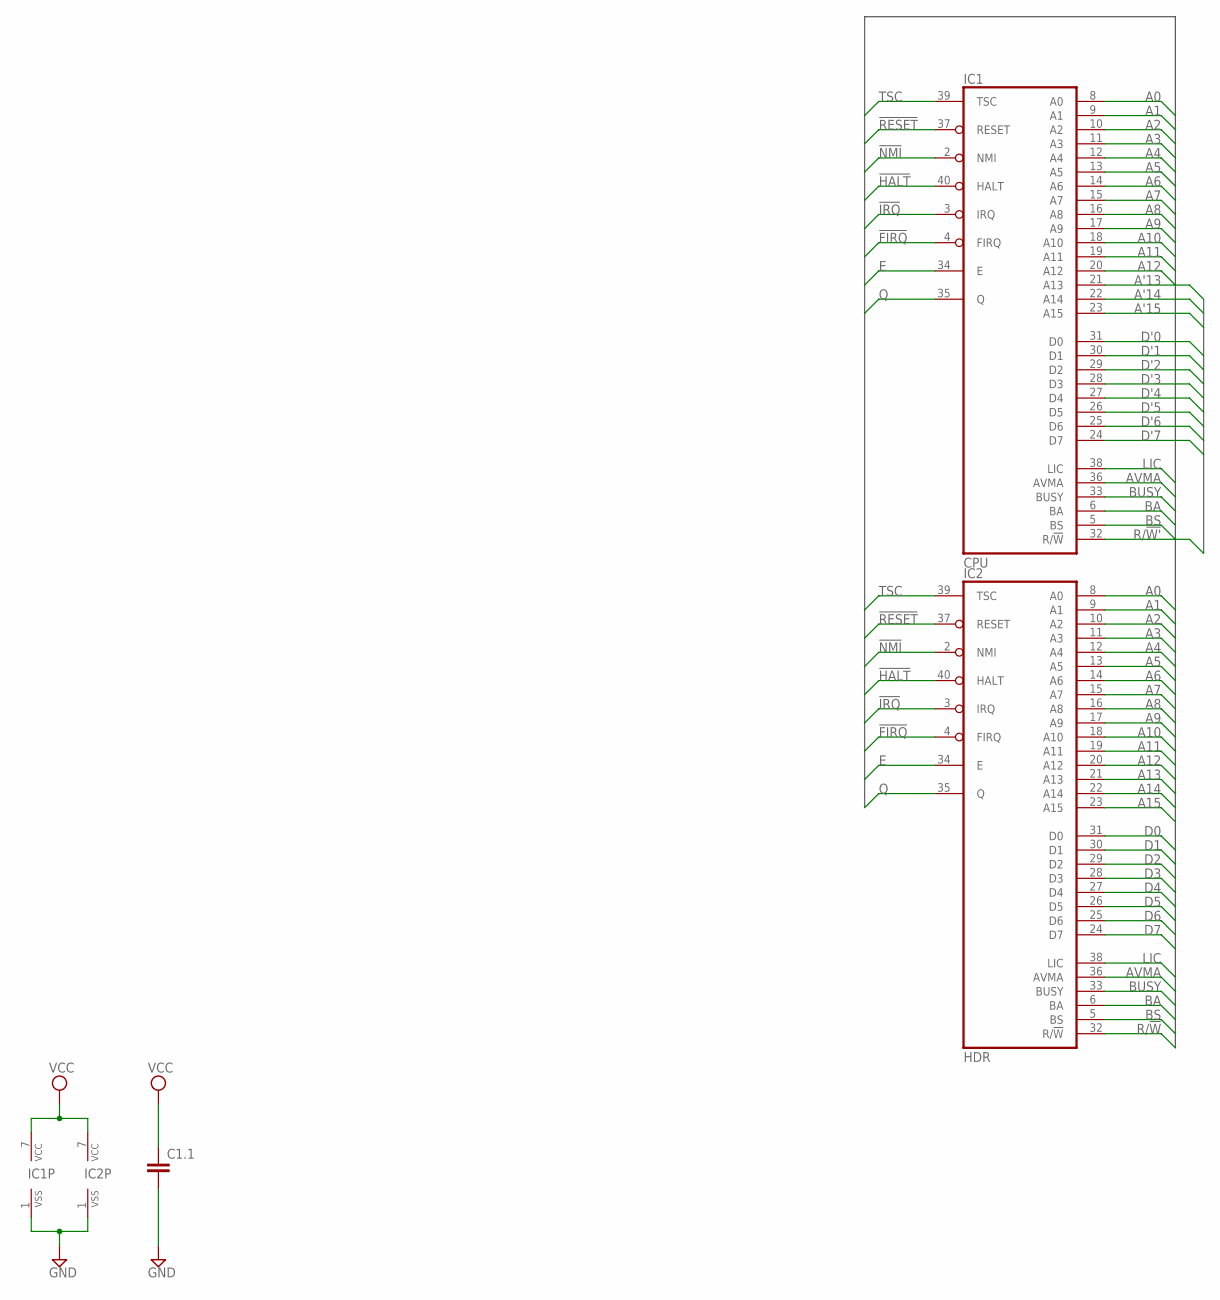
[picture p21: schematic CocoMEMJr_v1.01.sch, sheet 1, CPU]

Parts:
C1.1: C-EUC0402; C0402
IC1: CPU; DIL40-ROUNDPAD
IC2: HDR; DIL40-ROUNDPAD

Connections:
!FIRQ: IC1.4 (FIRQ), IC2.4 (FIRQ); also elsewhere on the board
!HALT: IC1.40 (HALT), IC2.40 (HALT); also elsewhere on the board
!IRQ: IC1.3 (IRQ), IC2.3 (IRQ); also elsewhere on the board
!NMI: IC1.2 (NMI), IC2.2 (NMI); also elsewhere on the board
!RESET: IC1.37 (RESET), IC2.37 (RESET); also elsewhere on the board
A0: IC1.8 (A0), IC2.8 (A0); also elsewhere on the board
A1: IC1.9 (A1), IC2.9 (A1); also elsewhere on the board
A2: IC1.10 (A2), IC2.10 (A2); also elsewhere on the board
A3: IC1.11 (A3), IC2.11 (A3); also elsewhere on the board
A4: IC1.12 (A4), IC2.12 (A4); also elsewhere on the board
A5: IC1.13 (A5), IC2.13 (A5); also elsewhere on the board
A6: IC1.14 (A6), IC2.14 (A6); also elsewhere on the board
A7: IC1.15 (A7), IC2.15 (A7); also elsewhere on the board
A8: IC1.16 (A8), IC2.16 (A8); also elsewhere on the board
A9: IC1.17 (A9), IC2.17 (A9); also elsewhere on the board
A10: IC1.18 (A10), IC2.18 (A10); also elsewhere on the board
A11: IC1.19 (A11), IC2.19 (A11); also elsewhere on the board
A12: IC1.20 (A12), IC2.20 (A12); also elsewhere on the board
A13: IC2.21 (A13); also elsewhere on the board
A14: IC2.22 (A14); also elsewhere on the board
A15: IC2.23 (A15); also elsewhere on the board
A'13: IC1.21 (A13); also elsewhere on the board
A'14: IC1.22 (A14); also elsewhere on the board
A'15: IC1.23 (A15); also elsewhere on the board
AVMA: IC1.36 (AVMA), IC2.36 (AVMA)
BA: IC1.6 (BA), IC2.6 (BA); also elsewhere on the board
BS: IC1.5 (BS), IC2.5 (BS); also elsewhere on the board
BUSY: IC1.33 (BUSY), IC2.33 (BUSY); also elsewhere on the board
D0: IC2.31 (D0); also elsewhere on the board
D1: IC2.30 (D1); also elsewhere on the board
D2: IC2.29 (D2); also elsewhere on the board
D3: IC2.28 (D3); also elsewhere on the board
D4: IC2.27 (D4); also elsewhere on the board
D5: IC2.26 (D5); also elsewhere on the board
D6: IC2.25 (D6); also elsewhere on the board
D7: IC2.24 (D7); also elsewhere on the board
D'0: IC1.31 (D0); also elsewhere on the board
D'1: IC1.30 (D1); also elsewhere on the board
D'2: IC1.29 (D2); also elsewhere on the board
D'3: IC1.28 (D3); also elsewhere on the board
D'4: IC1.27 (D4); also elsewhere on the board
D'5: IC1.26 (D5); also elsewhere on the board
D'6: IC1.25 (D6); also elsewhere on the board
D'7: IC1.24 (D7); also elsewhere on the board
E: IC1.34 (E), IC2.34 (E); also elsewhere on the board
GND: C1.1.2, IC1.1 (VSS), IC2.1 (VSS); also elsewhere on the board
LIC: IC1.38 (LIC), IC2.38 (LIC); also elsewhere on the board
Q: IC1.35 (Q), IC2.35 (Q); also elsewhere on the board
R/!W: IC2.32 (R/!W); also elsewhere on the board
R/!W': IC1.32 (R/!W); also elsewhere on the board
TSC: IC1.39 (TSC), IC2.39 (TSC); also elsewhere on the board
VCC: C1.1.1, IC1.7 (VCC), IC2.7 (VCC); also elsewhere on the board

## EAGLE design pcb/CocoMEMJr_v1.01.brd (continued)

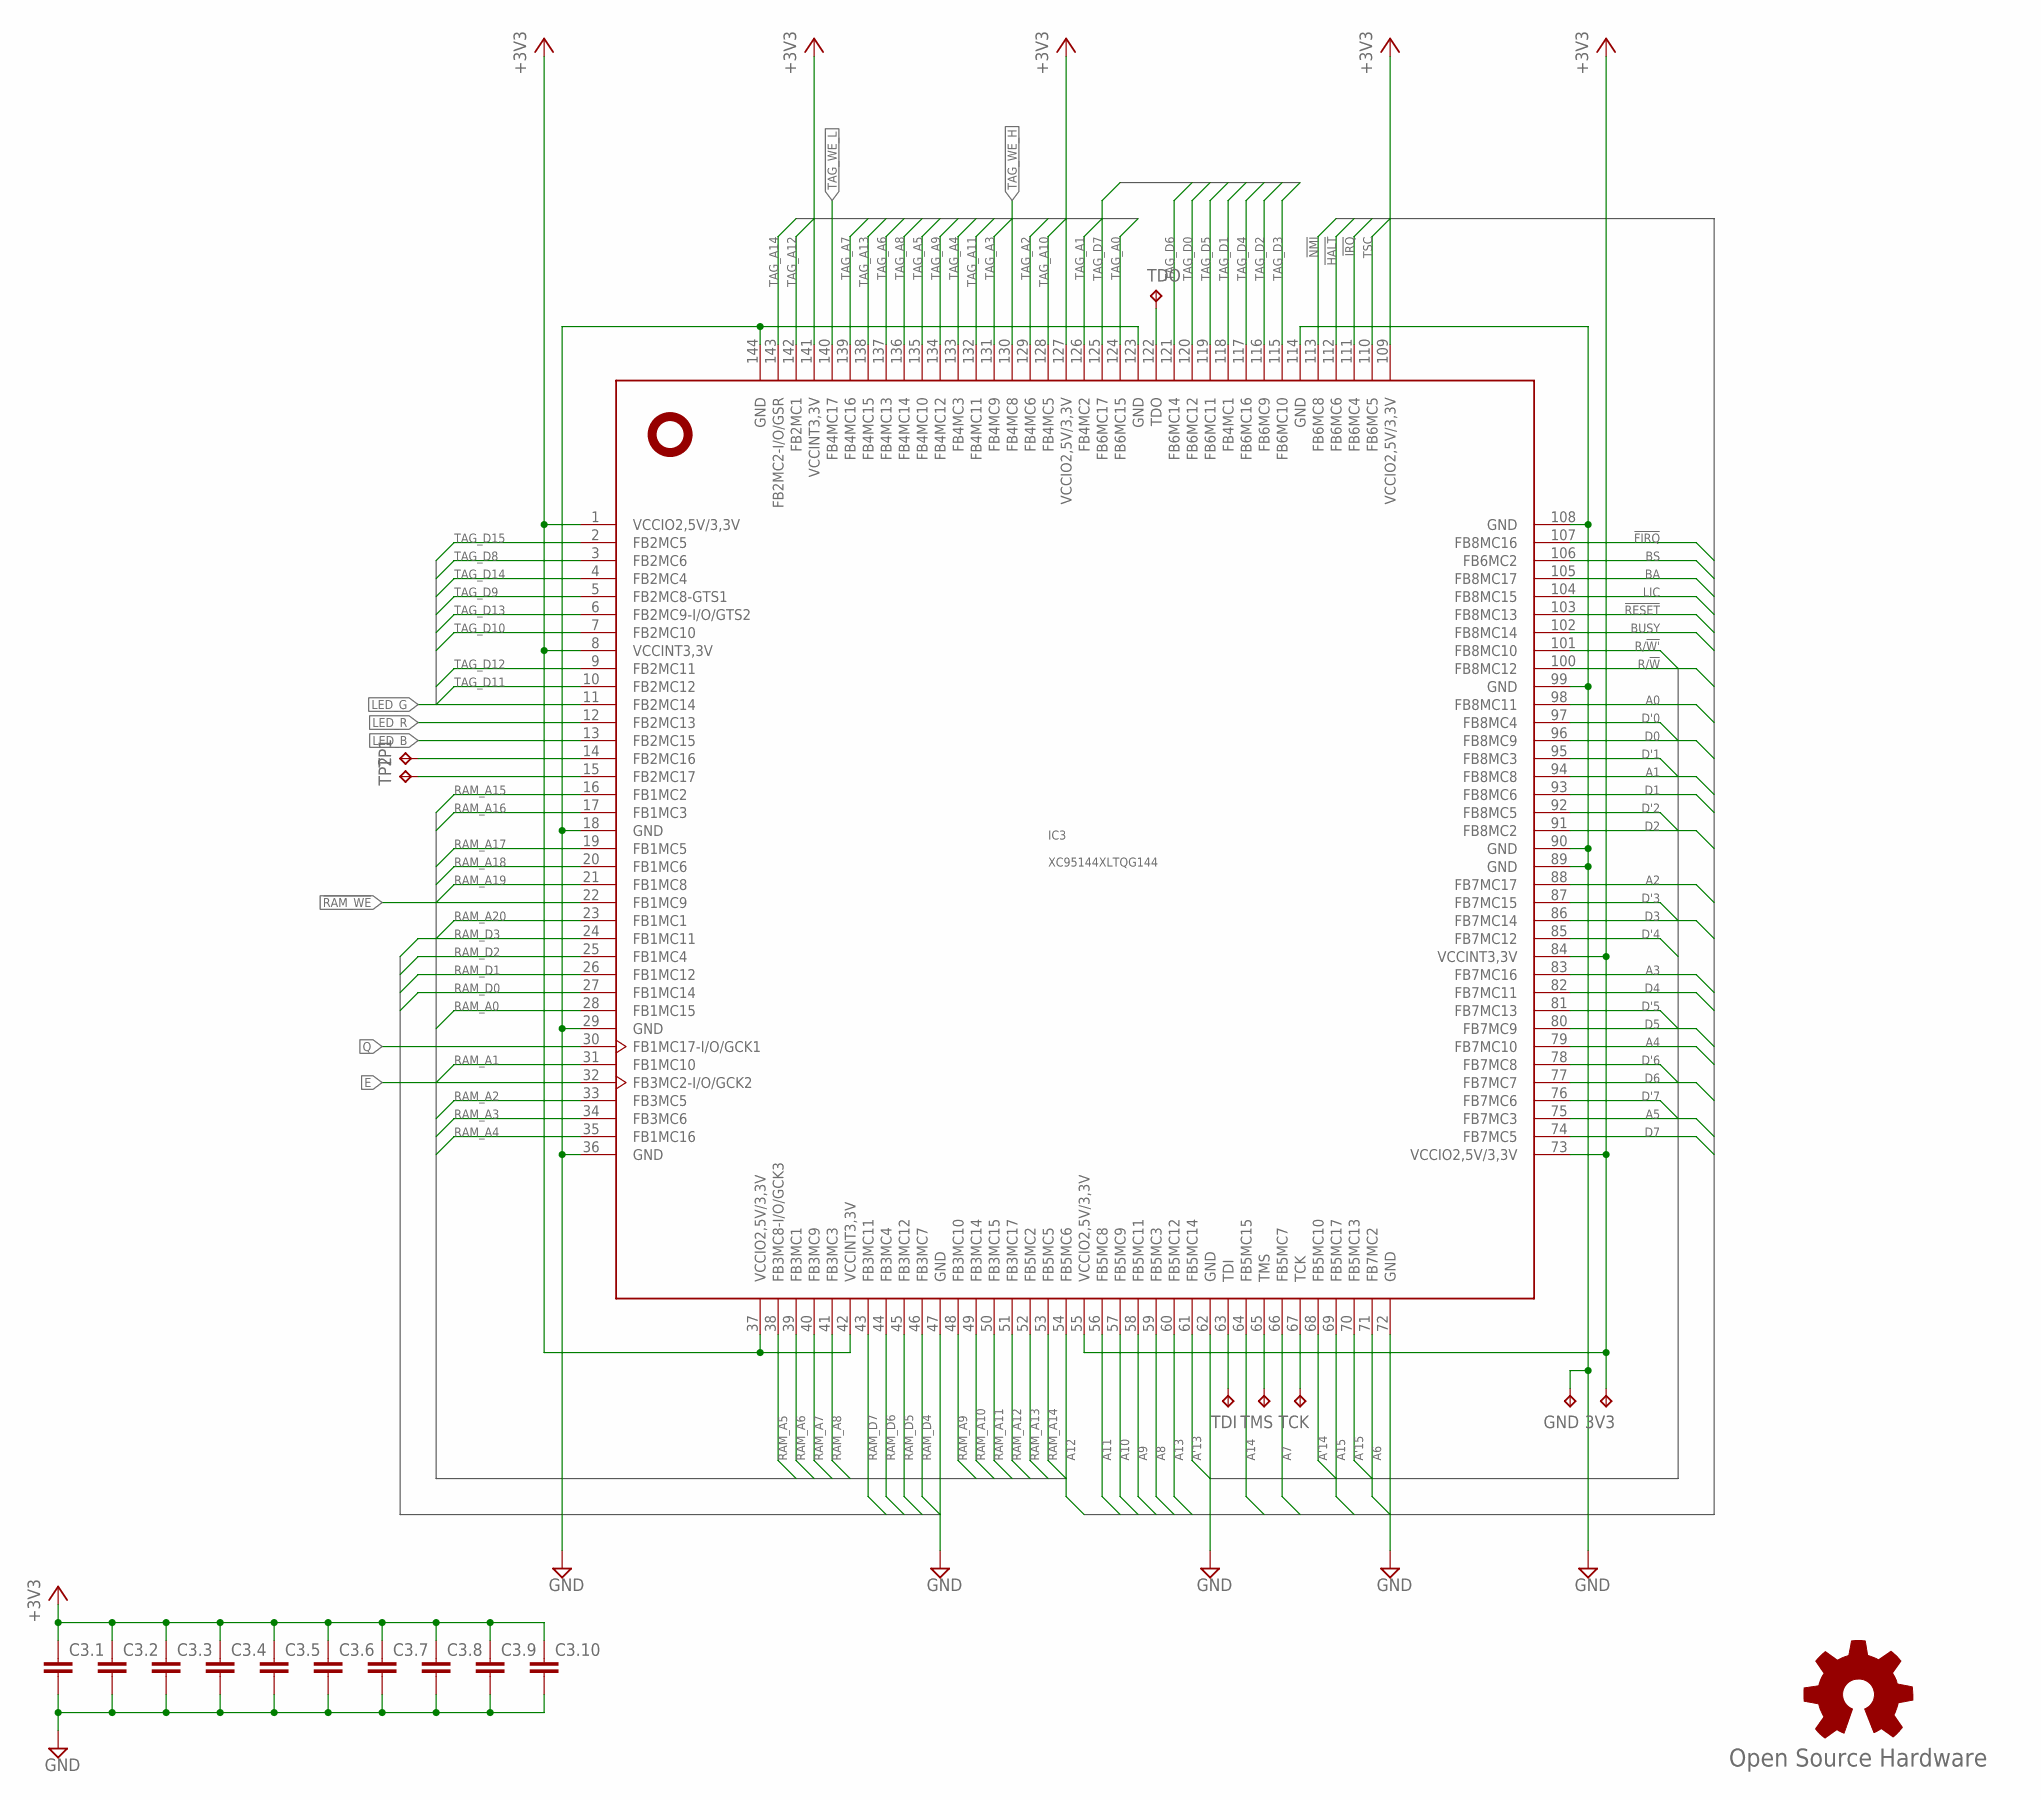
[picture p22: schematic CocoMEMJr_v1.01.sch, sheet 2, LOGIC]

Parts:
3V3: TPTP08R; TP08R
C3.1, C3.2, C3.3, C3.4, C3.5, C3.6, C3.7, C3.8, C3.9, C3.10: C-EUC0402; C0402
GND: TPTP08R; TP08R
GOLD_ORB_SM1: Open Source Hardware; OSHW_5MM
IC3: XC95144XLTQG144; TQFP144
TCK: TPTP08R; TP08R
TDI: TPTP08R; TP08R
TDO: TPTP08R; TP08R
TMS: TPTP08R; TP08R
TP1, TP2: TPTP08R; TP08R

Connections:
!FIRQ: IC3.107 (FB8MC16); also elsewhere on the board
!HALT: IC3.112 (FB6MC6); also elsewhere on the board
!IRQ: IC3.111 (FB6MC4); also elsewhere on the board
!NMI: IC3.113 (FB6MC8); also elsewhere on the board
!RAM_WE: IC3.22 (FB1MC9); also elsewhere on the board
!RESET: IC3.103 (FB8MC13); also elsewhere on the board
!TAG_WE_H: IC3.130 (FB4MC8); also elsewhere on the board
!TAG_WE_L: IC3.140 (FB4MC17); also elsewhere on the board
+3V3: 3V3.TP, C3.1.1, C3.2.1, C3.3.1, C3.4.1, C3.5.1, C3.6.1, C3.7.1, C3.8.1, C3.9.1, C3.10.1, IC3.1 (VCCIO2,5V/3,3V), IC3.8 (VCCINT3,3V), IC3.37 (VCCIO2,5V/3,3V), IC3.42 (VCCINT3,3V), IC3.55 (VCCIO2,5V/3,3V), IC3.73 (VCCIO2,5V/3,3V), IC3.84 (VCCINT3,3V), IC3.109 (VCCIO2,5V/3,3V), IC3.127 (VCCIO2,5V/3,3V), IC3.141 (VCCINT3,3V); also elsewhere on the board
A0: IC3.98 (FB8MC11); also elsewhere on the board
A1: IC3.94 (FB8MC8); also elsewhere on the board
A2: IC3.88 (FB7MC17); also elsewhere on the board
A3: IC3.83 (FB7MC16); also elsewhere on the board
A4: IC3.79 (FB7MC10); also elsewhere on the board
A5: IC3.75 (FB7MC3); also elsewhere on the board
A6: IC3.71 (FB7MC2); also elsewhere on the board
A7: IC3.66 (FB5MC7); also elsewhere on the board
A8: IC3.59 (FB5MC3); also elsewhere on the board
A9: IC3.58 (FB5MC11); also elsewhere on the board
A10: IC3.57 (FB5MC9); also elsewhere on the board
A11: IC3.56 (FB5MC8); also elsewhere on the board
A12: IC3.54 (FB5MC6); also elsewhere on the board
A13: IC3.60 (FB5MC12); also elsewhere on the board
A14: IC3.64 (FB5MC15); also elsewhere on the board
A15: IC3.69 (FB5MC17); also elsewhere on the board
A'13: IC3.61 (FB5MC14); also elsewhere on the board
A'14: IC3.68 (FB5MC10); also elsewhere on the board
A'15: IC3.70 (FB5MC13); also elsewhere on the board
BA: IC3.105 (FB8MC17); also elsewhere on the board
BS: IC3.106 (FB6MC2); also elsewhere on the board
BUSY: IC3.102 (FB8MC14); also elsewhere on the board
D0: IC3.96 (FB8MC9); also elsewhere on the board
D1: IC3.93 (FB8MC6); also elsewhere on the board
D2: IC3.91 (FB8MC2); also elsewhere on the board
D3: IC3.86 (FB7MC14); also elsewhere on the board
D4: IC3.82 (FB7MC11); also elsewhere on the board
D5: IC3.80 (FB7MC9); also elsewhere on the board
D6: IC3.77 (FB7MC7); also elsewhere on the board
D7: IC3.74 (FB7MC5); also elsewhere on the board
D'0: IC3.97 (FB8MC4); also elsewhere on the board
D'1: IC3.95 (FB8MC3); also elsewhere on the board
D'2: IC3.92 (FB8MC5); also elsewhere on the board
D'3: IC3.87 (FB7MC15); also elsewhere on the board
D'4: IC3.85 (FB7MC12); also elsewhere on the board
D'5: IC3.81 (FB7MC13); also elsewhere on the board
D'6: IC3.78 (FB7MC8); also elsewhere on the board
D'7: IC3.76 (FB7MC6); also elsewhere on the board
E: IC3.32 (FB3MC2-I/O/GCK2); also elsewhere on the board
GND: C3.1.2, C3.2.2, C3.3.2, C3.4.2, C3.5.2, C3.6.2, C3.7.2, C3.8.2, C3.9.2, C3.10.2, GND.TP, IC3.18 (GND), IC3.29 (GND), IC3.36 (GND), IC3.47 (GND), IC3.62 (GND), IC3.72 (GND), IC3.89 (GND), IC3.90 (GND), IC3.99 (GND), IC3.108 (GND), IC3.114 (GND), IC3.123 (GND), IC3.144 (GND); also elsewhere on the board
LED_B: IC3.13 (FB2MC15); also elsewhere on the board
LED_G: IC3.11 (FB2MC14); also elsewhere on the board
LED_R: IC3.12 (FB2MC13); also elsewhere on the board
LIC: IC3.104 (FB8MC15); also elsewhere on the board
unnamed: IC3.14 (FB2MC16), TP1.TP
unnamed: IC3.63 (TDI), TDI.TP
unnamed: IC3.65 (TMS), TMS.TP
unnamed: IC3.67 (TCK), TCK.TP
unnamed: IC3.122 (TDO), TDO.TP
unnamed: IC3.15 (FB2MC17), TP2.TP
Q: IC3.30 (FB1MC17-I/O/GCK1); also elsewhere on the board
R/!W: IC3.100 (FB8MC12); also elsewhere on the board
R/!W': IC3.101 (FB8MC10); also elsewhere on the board
RAM_A0: IC3.28 (FB1MC15); also elsewhere on the board
RAM_A1: IC3.31 (FB1MC10); also elsewhere on the board
RAM_A2: IC3.33 (FB3MC5); also elsewhere on the board
RAM_A3: IC3.34 (FB3MC6); also elsewhere on the board
RAM_A4: IC3.35 (FB1MC16); also elsewhere on the board
RAM_A5: IC3.38 (FB3MC8-I/O/GCK3); also elsewhere on the board
RAM_A6: IC3.39 (FB3MC1); also elsewhere on the board
RAM_A7: IC3.40 (FB3MC9); also elsewhere on the board
RAM_A8: IC3.41 (FB3MC3); also elsewhere on the board
RAM_A9: IC3.48 (FB3MC10); also elsewhere on the board
RAM_A10: IC3.49 (FB3MC14); also elsewhere on the board
RAM_A11: IC3.50 (FB3MC15); also elsewhere on the board
RAM_A12: IC3.51 (FB3MC17); also elsewhere on the board
RAM_A13: IC3.52 (FB5MC2); also elsewhere on the board
RAM_A14: IC3.53 (FB5MC5); also elsewhere on the board
RAM_A15: IC3.16 (FB1MC2); also elsewhere on the board
RAM_A16: IC3.17 (FB1MC3); also elsewhere on the board
RAM_A17: IC3.19 (FB1MC5); also elsewhere on the board
RAM_A18: IC3.20 (FB1MC6); also elsewhere on the board
RAM_A19: IC3.21 (FB1MC8); also elsewhere on the board
RAM_A20: IC3.23 (FB1MC1); also elsewhere on the board
RAM_D0: IC3.27 (FB1MC14); also elsewhere on the board
RAM_D1: IC3.26 (FB1MC12); also elsewhere on the board
RAM_D2: IC3.25 (FB1MC4); also elsewhere on the board
RAM_D3: IC3.24 (FB1MC11); also elsewhere on the board
RAM_D4: IC3.46 (FB3MC7); also elsewhere on the board
RAM_D5: IC3.45 (FB3MC12); also elsewhere on the board
RAM_D6: IC3.44 (FB3MC4); also elsewhere on the board
RAM_D7: IC3.43 (FB3MC11); also elsewhere on the board
TAG_A0: IC3.124 (FB6MC15); also elsewhere on the board
TAG_A1: IC3.126 (FB4MC2); also elsewhere on the board
TAG_A2: IC3.129 (FB4MC6); also elsewhere on the board
TAG_A3: IC3.131 (FB4MC9); also elsewhere on the board
TAG_A4: IC3.133 (FB4MC3); also elsewhere on the board
TAG_A5: IC3.135 (FB4MC10); also elsewhere on the board
TAG_A6: IC3.137 (FB4MC13); also elsewhere on the board
TAG_A7: IC3.139 (FB4MC16); also elsewhere on the board
TAG_A8: IC3.136 (FB4MC14); also elsewhere on the board
TAG_A9: IC3.134 (FB4MC12); also elsewhere on the board
TAG_A10: IC3.128 (FB4MC5); also elsewhere on the board
TAG_A11: IC3.132 (FB4MC11); also elsewhere on the board
TAG_A12: IC3.142 (FB2MC1); also elsewhere on the board
TAG_A13: IC3.138 (FB4MC15); also elsewhere on the board
TAG_A14: IC3.143 (FB2MC2-I/O/GSR); also elsewhere on the board
TAG_D0: IC3.120 (FB6MC12); also elsewhere on the board
TAG_D1: IC3.118 (FB4MC1); also elsewhere on the board
TAG_D2: IC3.116 (FB6MC9); also elsewhere on the board
TAG_D3: IC3.115 (FB6MC10); also elsewhere on the board
TAG_D4: IC3.117 (FB6MC16); also elsewhere on the board
TAG_D5: IC3.119 (FB6MC11); also elsewhere on the board
TAG_D6: IC3.121 (FB6MC14); also elsewhere on the board
TAG_D7: IC3.125 (FB6MC17); also elsewhere on the board
TAG_D8: IC3.3 (FB2MC6); also elsewhere on the board
TAG_D9: IC3.5 (FB2MC8-GTS1); also elsewhere on the board
TAG_D10: IC3.7 (FB2MC10); also elsewhere on the board
TAG_D11: IC3.10 (FB2MC12); also elsewhere on the board
TAG_D12: IC3.9 (FB2MC11); also elsewhere on the board
TAG_D13: IC3.6 (FB2MC9-I/O/GTS2); also elsewhere on the board
TAG_D14: IC3.4 (FB2MC4); also elsewhere on the board
TAG_D15: IC3.2 (FB2MC5); also elsewhere on the board
TSC: IC3.110 (FB6MC5); also elsewhere on the board

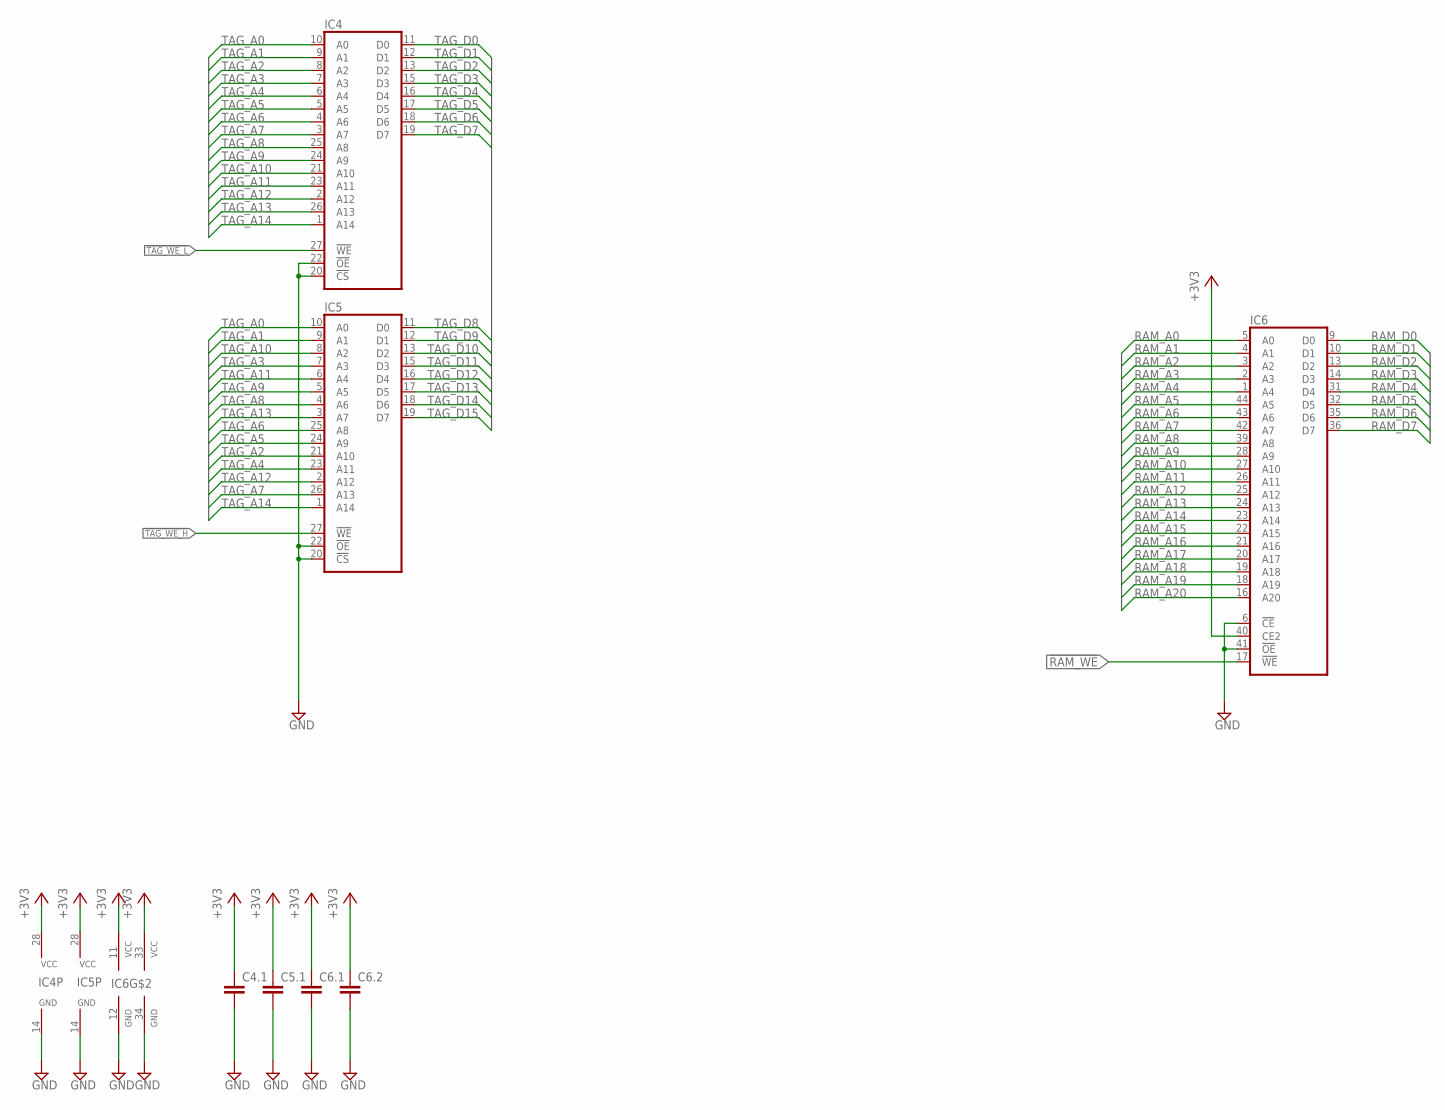
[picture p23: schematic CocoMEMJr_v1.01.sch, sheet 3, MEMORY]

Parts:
C4.1, C5.1, C6.1, C6.2: C-EUC0402; C0402
IC4, IC5: JEDEC_32KB_SRAMY; SOJ32/3
IC6: AS6C1608-XXTIN; TSOP44-II

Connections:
!RAM_WE: IC6.17 (!WE); also elsewhere on the board
!TAG_WE_H: IC5.27 (!WE); also elsewhere on the board
!TAG_WE_L: IC4.27 (!WE); also elsewhere on the board
+3V3: C4.1.1, C5.1.1, C6.1.1, C6.2.1, IC4.28 (VCC), IC5.28 (VCC), IC6.11 (VCC), IC6.33 (VCC), IC6.40 (CE2); also elsewhere on the board
GND: C4.1.2, C5.1.2, C6.1.2, C6.2.2, IC4.14 (GND), IC4.20 (!CS), IC4.22 (!OE), IC5.14 (GND), IC5.20 (!CS), IC5.22 (!OE), IC6.6 (!CE), IC6.12 (GND), IC6.34 (GND), IC6.41 (!OE); also elsewhere on the board
RAM_A0: IC6.5 (A0); also elsewhere on the board
RAM_A1: IC6.4 (A1); also elsewhere on the board
RAM_A2: IC6.3 (A2); also elsewhere on the board
RAM_A3: IC6.2 (A3); also elsewhere on the board
RAM_A4: IC6.1 (A4); also elsewhere on the board
RAM_A5: IC6.44 (A5); also elsewhere on the board
RAM_A6: IC6.43 (A6); also elsewhere on the board
RAM_A7: IC6.42 (A7); also elsewhere on the board
RAM_A8: IC6.39 (A8); also elsewhere on the board
RAM_A9: IC6.28 (A9); also elsewhere on the board
RAM_A10: IC6.27 (A10); also elsewhere on the board
RAM_A11: IC6.26 (A11); also elsewhere on the board
RAM_A12: IC6.25 (A12); also elsewhere on the board
RAM_A13: IC6.24 (A13); also elsewhere on the board
RAM_A14: IC6.23 (A14); also elsewhere on the board
RAM_A15: IC6.22 (A15); also elsewhere on the board
RAM_A16: IC6.21 (A16); also elsewhere on the board
RAM_A17: IC6.20 (A17); also elsewhere on the board
RAM_A18: IC6.19 (A18); also elsewhere on the board
RAM_A19: IC6.18 (A19); also elsewhere on the board
RAM_A20: IC6.16 (A20); also elsewhere on the board
RAM_D0: IC6.9 (D0); also elsewhere on the board
RAM_D1: IC6.10 (D1); also elsewhere on the board
RAM_D2: IC6.13 (D2); also elsewhere on the board
RAM_D3: IC6.14 (D3); also elsewhere on the board
RAM_D4: IC6.31 (D4); also elsewhere on the board
RAM_D5: IC6.32 (D5); also elsewhere on the board
RAM_D6: IC6.35 (D6); also elsewhere on the board
RAM_D7: IC6.36 (D7); also elsewhere on the board
TAG_A0: IC4.10 (A0), IC5.10 (A0); also elsewhere on the board
TAG_A1: IC4.9 (A1), IC5.9 (A1); also elsewhere on the board
TAG_A2: IC4.8 (A2), IC5.21 (A10); also elsewhere on the board
TAG_A3: IC4.7 (A3), IC5.7 (A3); also elsewhere on the board
TAG_A4: IC4.6 (A4), IC5.23 (A11); also elsewhere on the board
TAG_A5: IC4.5 (A5), IC5.24 (A9); also elsewhere on the board
TAG_A6: IC4.4 (A6), IC5.25 (A8); also elsewhere on the board
TAG_A7: IC4.3 (A7), IC5.26 (A13); also elsewhere on the board
TAG_A8: IC4.25 (A8), IC5.4 (A6); also elsewhere on the board
TAG_A9: IC4.24 (A9), IC5.5 (A5); also elsewhere on the board
TAG_A10: IC4.21 (A10), IC5.8 (A2); also elsewhere on the board
TAG_A11: IC4.23 (A11), IC5.6 (A4); also elsewhere on the board
TAG_A12: IC4.2 (A12), IC5.2 (A12); also elsewhere on the board
TAG_A13: IC4.26 (A13), IC5.3 (A7); also elsewhere on the board
TAG_A14: IC4.1 (A14), IC5.1 (A14); also elsewhere on the board
TAG_D0: IC4.11 (D0); also elsewhere on the board
TAG_D1: IC4.12 (D1); also elsewhere on the board
TAG_D2: IC4.13 (D2); also elsewhere on the board
TAG_D3: IC4.15 (D3); also elsewhere on the board
TAG_D4: IC4.16 (D4); also elsewhere on the board
TAG_D5: IC4.17 (D5); also elsewhere on the board
TAG_D6: IC4.18 (D6); also elsewhere on the board
TAG_D7: IC4.19 (D7); also elsewhere on the board
TAG_D8: IC5.11 (D0); also elsewhere on the board
TAG_D9: IC5.12 (D1); also elsewhere on the board
TAG_D10: IC5.13 (D2); also elsewhere on the board
TAG_D11: IC5.15 (D3); also elsewhere on the board
TAG_D12: IC5.16 (D4); also elsewhere on the board
TAG_D13: IC5.17 (D5); also elsewhere on the board
TAG_D14: IC5.18 (D6); also elsewhere on the board
TAG_D15: IC5.19 (D7); also elsewhere on the board

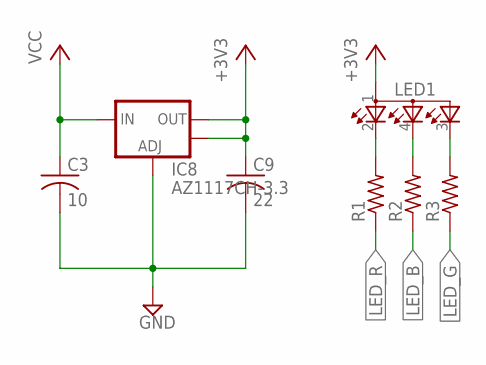
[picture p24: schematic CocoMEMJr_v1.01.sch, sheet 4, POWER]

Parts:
C3: 10; C0805
C9: 22; C0805
IC8: AZ1117CH-3.3; SOT223
LED1: RGBLED-PLCC4; PLCC-4
R1, R2, R3: R-US_R0402; R0402

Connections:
+3V3: C9.1, IC8.2 (OUT), IC8.4 (OUT), LED1.1 (A2); also elsewhere on the board
GND: C3.2, C9.2, IC8.1 (ADJ); also elsewhere on the board
LED_B: R2.1; also elsewhere on the board
LED_G: R3.1; also elsewhere on the board
LED_R: R1.1; also elsewhere on the board
unnamed: LED1.2 (CRED), R1.2
unnamed: LED1.4 (CBLUE), R2.2
unnamed: LED1.3 (CGREEN), R3.2
VCC: C3.1, IC8.3 (IN); also elsewhere on the board

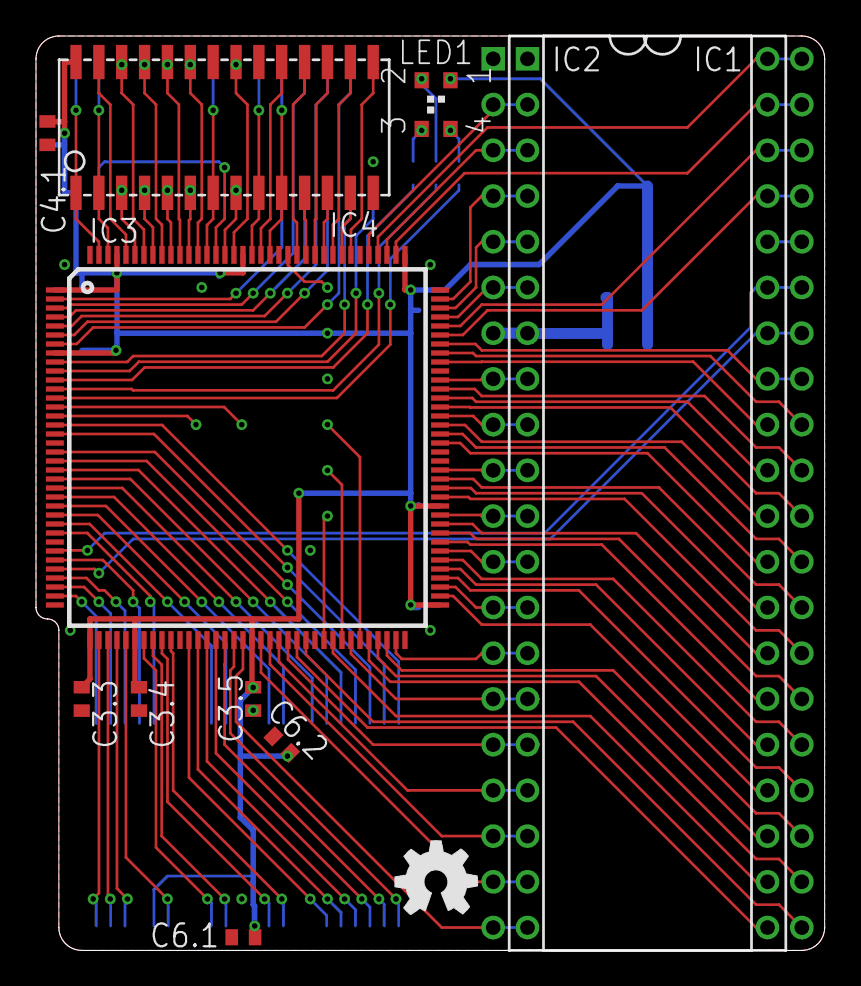
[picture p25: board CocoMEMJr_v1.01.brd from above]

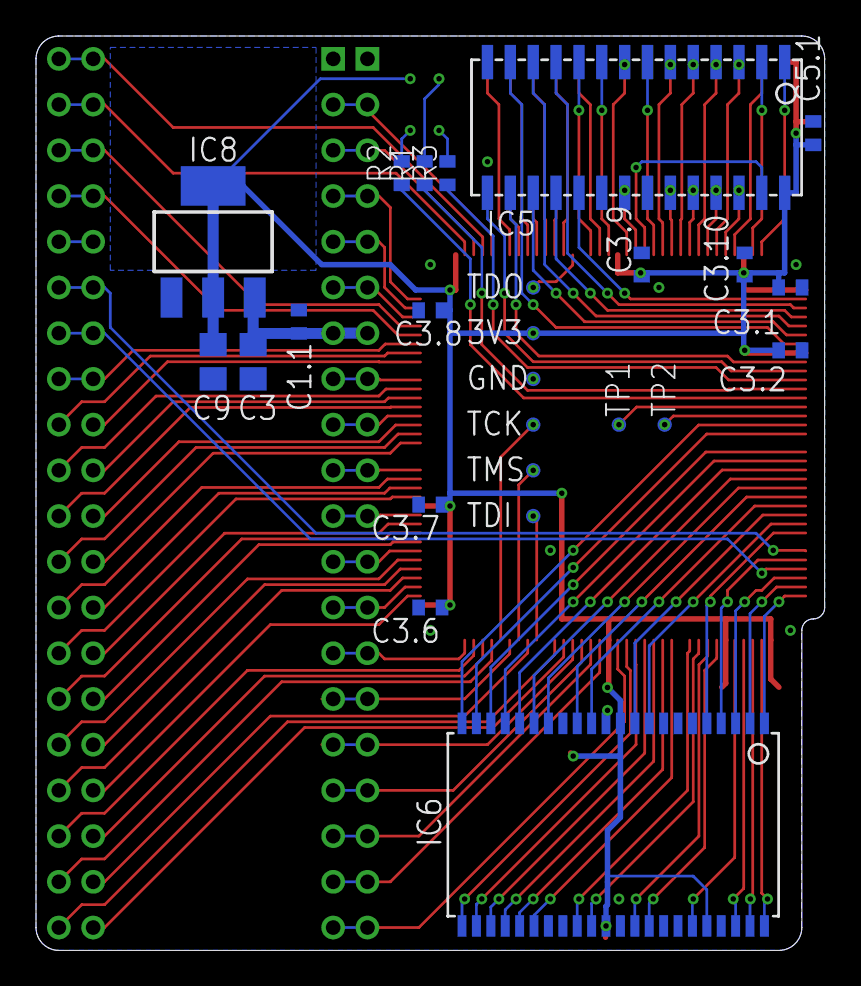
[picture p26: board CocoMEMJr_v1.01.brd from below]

Board: 2 copper layers, 43.8 x 50.8 mm, 37 parts (25 on the bottom side), 128 nets.

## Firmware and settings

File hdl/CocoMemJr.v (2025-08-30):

`timescale 1ns / 1ps
//////////////////////////////////////////////////////////////////////////////////
// Company: 
// Engineer: 
// 
// Create Date:    23:29:06 03/23/2018 
// Design Name: 
// Module Name:    CocoMemJr 
// Project Name: 
// Target Devices: 
// Tool versions: 
// Description: 
//
// Dependencies: 
//
// Revision: 
// Revision 0.01 - File Created
// Additional Comments: 
//
//////////////////////////////////////////////////////////////////////////////////
module CocoMemJr(
					  input _reset,
                 input e,
                 input q,
					  input ba,
                 input r_w_cpu,
                 input [15:0]address_cpu,
                 inout [7:0]data_cpu,
                 output r_w_brd,
                 output [15:13]address_brd,
                 inout [7:0]data_brd,
                 output _we_dat_l,
                 output _we_dat_h,
                 output [14:0]address_dat,
                 inout [15:0]data_dat,
					  output _we_mem,
					  output [20:0]address_mem,
					  inout [7:0]data_mem,
					  output [2:0]bank,
					  output _irq,
					  output _firq
					 );


wire ce_fxxx;
wire ce_ffxx;
wire ce_fexx;
wire ce_crm;
wire ce_mmu_regs;
wire ce_init0;
wire ce_init1;
wire ce_dat;
wire ce_mem;
wire we_dat_l;
wire we_dat_h;

wire flag_mmu_enabled;
wire flag_crm_enabled;
wire [3:0]cfg_mem;
wire [2:0]cfg_vdg;
wire dat_task_active; 						// 1 bit of task register for now.

reg [20:13]address_out;
reg [4:0]address_dat_out;
reg [7:0]data_out;

assign _irq = 									1'bz;
assign _firq = 								1'bz;

// fexx or ffxx
assign ce_fxxx =                       (address_cpu[15:9] == 7'b1111111); 			
assign ce_fexx =                       ce_fxxx & (address_cpu[8] == 0);
assign ce_ffxx =                       ce_fxxx & (address_cpu[8] == 1);	
//ff9x
assign ce_mmu_regs =                   ce_ffxx & (address_cpu[7:4] == 4'h9);
//ff90
assign ce_init0 =                      ce_mmu_regs & (address_cpu[3:0] == 4'h0);
//ff91
assign ce_init1 =                      ce_mmu_regs & (address_cpu[3:0] == 4'h1);

//ffax
assign ce_dat =                        ce_ffxx & (address_cpu[7:4] == 4'ha);
//if CRM enabled, and ffex
assign ce_crm =                        flag_crm_enabled & ce_fexx;

assign ce_ffcx = 								ce_ffxx & (address_cpu[7:4] == 4'hc);
assign ce_ffdx = 								ce_ffxx & (address_cpu[7:4] == 4'hd);

/*
	There's a nuance here. If we're using internal memory, the simple approach
	is to open a hole in the memory map for the motherboard 64kB RAM (in this
	design, we've put this at the bottom of the physical address space), and 
	use internal memory when the virtual address is not ffxx and the address is
	not in the lowest 64kB. 
	
	However, that introduces a bug if the programmer maps the $3f bank (top
	8kB of motherboard RAM space) into a bank where the top 256 bytes can be
	written (any bank except the top one, in effect). For example, let's say
	bank $3f is mapped into $ffa0. The code then accesses the top 8kB of
	motherboard RAM (or ROM) via an access to $0000-$1fff. All is well until
	we get to $1f00. The code reads from $1f00, the DAT converts that to $ff00,
   and tries to read from $fff0 on the motherboard, expecting a RAM read. But,
	$ffxx is IO and vectors, so the SAM reads from IO. 

	To counteract that, this design creates a 256 byte RAM mirror in internal
	RAM for that space.  So, if code is not explicitly accessing ffxx, but the
	translated address is ffxx, read/write from internal memory.
 */

assign flag_cocoram =						(address_out[20:16] == 5'b0);
assign ce_mem =               			(!flag_cocoram
													 | (flag_cocoram
   													 && (address_out[15:13] == 3'b111)
														 && (address_cpu[12:8] == 5'b11111)
														 && !ce_ffxx
														)
													);   // hole at bank 00-07 for main memory

assign we_mem =                        e                    // top half of E
                                       & !r_w_cpu           // write cycle
                                       & ce_mem;    			// anything but pages 0-7
													

assign we_dat_l =                      e                    // top half of E
                                       & !r_w_cpu           // write cycle
                                       & ce_dat;  
assign we_dat_h = 							0;

assign _we_dat_l =                     !we_dat_l;
assign _we_dat_h =                     !we_dat_h;
assign _we_mem = 								!we_mem;

assign data_brd =                      (!ce_mem & !ba & !r_w_cpu & (e | q) ? data_cpu : 8'bz);
assign data_mem =                      (ce_mem & !ba & !r_w_cpu & (e | q) ? data_cpu : 8'bz);
assign data_cpu =                      (r_w_cpu ? data_out : 8'bz);
// might need !ba on these, not sure
assign data_dat[7:0] =                 (we_dat_l ? data_cpu : 8'bz);
assign data_dat[15:8] =                (we_dat_h ? data_cpu : 8'bz);

// we need write to only happen with ce_mem is inactive
assign r_w_brd =                       !(!ba & !r_w_cpu & !ce_mem) ;

assign address_dat[14:0] =             address_dat_out;
// we may need to set address_brd to ffff or something when mem is being read.
assign address_brd[15:13] =            (!ba & (e | q) ? address_out[15:13] : 3'bz);
//assign bank = 									address_out[18:16];
assign bank = 									address_out[18:16];
assign address_mem = 						{address_out, address_cpu[12:0]};

register #(.WIDTH(1))                  reg_mmu(e, !_reset, !r_w_cpu & ce_init0, data_cpu[6], flag_mmu_enabled);
register #(.WIDTH(1))                  reg_crm(e, !_reset, !r_w_cpu & ce_init0, data_cpu[3], flag_crm_enabled);
register #(.WIDTH(1))                  reg_dat_task_lo(e, !_reset, !r_w_cpu & ce_init1, data_cpu[0], dat_task_active);

register #(.WIDTH(4))                  reg_FFCX(!e, !_reset, r_w_cpu & ce_ffcx, address_cpu[3:0], cfg_mem);
register #(.WIDTH(3))                  reg_FFDX(!e, !_reset, r_w_cpu & ce_ffdx, address_cpu[2:0], cfg_vdg);

// data for CPU
always @(*)
begin
   if(ce_init0)                                 // if accessing mmu register init0
      data_out = {0,flag_mmu_enabled,2'b0,flag_crm_enabled,3'b0};
   else if(ce_init1)           						// read active task low bits
      data_out = {7'b0, dat_task_active}; 
   //else if(ce_task_hi)         						// read active task high bits
   //   data_out = {'b0, dat_task_active[11:5]}; 
   else if(ce_dat)              // read MMU task regs low bytes
      data_out = data_dat[7:0];
	else if(ce_mem)
	   data_out = data_mem;
	else	
		data_out = data_brd;
end

// address for DAT
always @(*)
begin
   if(ce_dat)                   // DAT register access
      address_dat_out = address_cpu[3:0];
   else                                         // DAT MMU usage
      address_dat_out = {dat_task_active, address_cpu[15:13]};
end

// Address for MEM (internal or otherwise)
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

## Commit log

2018-04-28 Potential bug if user sets $ffa7 or $ffaf to 0-7 page and CRM is on, data will be stored in $00:fexx, not $3f:fexx
    [CocoMemJr.v]
2018-11-14 Change Coco DRAM mapping from bank 0-7 to bank $38-$3f. Might need to change it back later.
    [CocoMEMJr_v1.01.sch]
2018-12-12 Fix errors introduced when moving internal DRAM from banks 0-7 to 38-3f
    [CocoMemJr.v]
2019-03-06 Fixed bug in ce_mem assignment (not qualifying with E clock)
    [CocoMemJr.v]
2019-04-14 Potentially fixed MMU register windowing issue
    [CocoMemJr.v]
2019-04-14 More fixes for MMU mapping
    [CocoMemJr.v]
2025-08-30 Simplify the design for debugging
    [CoCoMEM_RAM.brd, CoCoMEM_RAM.sch, CocoMEMJr_v1.00.sch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]

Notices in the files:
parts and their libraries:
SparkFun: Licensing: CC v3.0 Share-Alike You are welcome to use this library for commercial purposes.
